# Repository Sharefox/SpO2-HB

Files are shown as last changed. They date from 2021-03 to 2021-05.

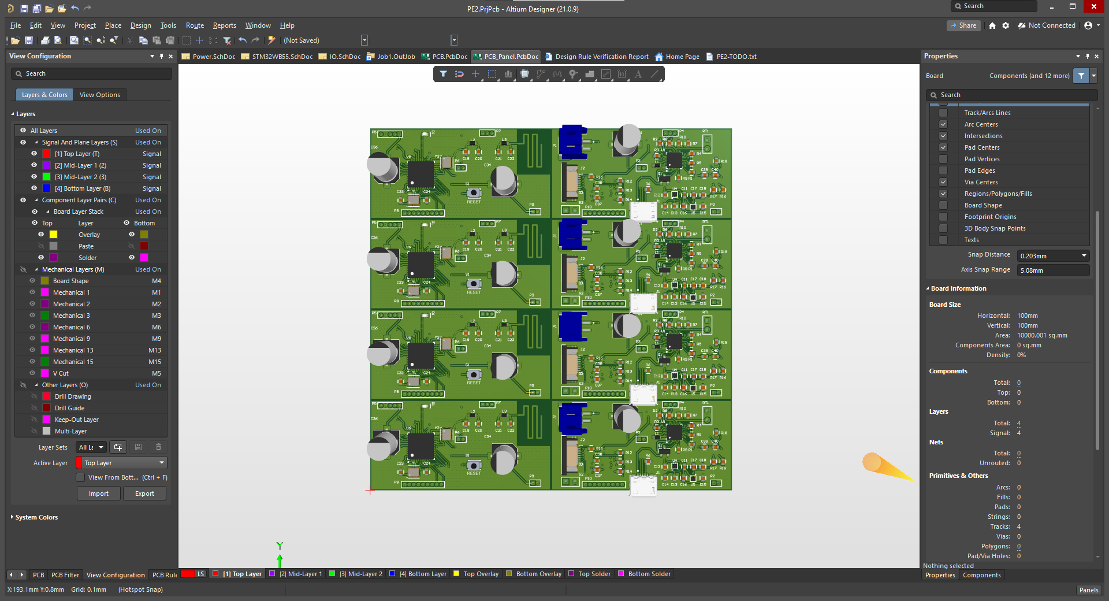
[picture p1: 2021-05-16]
PCB/PE2/Panel.png

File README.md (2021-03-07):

# SpO2/HB

 <br />
 <p align="center">
   <a href="https://github.com/Sharefox/SpO2-HB">
     
   </a>

   <h3 align="center">SpO2/HB measuring device</h3>

   <p align="center">
      Practice Enterprise 2 Heartbeat and Oxygen saturation sensor with Bluetooth functionality
     <br />
     <a href="https://github.com/Sharefox/SpO2-HB"><strong>Explore the docs »</strong></a>
     <br />
     <br />
     <a href="https://github.com/Sharefox/SpO2-HB">View Demo</a>
     ·
     <a href="https://github.com/Sharefox/SpO2-HB/issues">Report Bug</a>
     ·
     <a href="https://github.com/Sharefox/SpO2-HB/issues">Request Feature</a>
   </p>
 </p>

 <!-- TABLE OF CONTENTS -->
 <details open="open">
   <summary><h2 style="display: inline-block">Table of Contents</h2></summary>
   <ol>
     <li><a href="#about-the-project">About The Project</a></li>
     <li><a href="#usage">Usage</a></li>
     <li><a href="#roadmap">Roadmap</a></li>
     <li><a href="#contributing">Contributing</a></li>
     <li><a href="#license">License</a></li>
     <li><a href="#contact">Contact</a></li>
     <li><a href="#acknowledgements">Acknowledgements</a></li>
   </ol>
 </details>

 <!-- ABOUT THE PROJECT -->
## About The Project

 [![Product Name Screen Shot][product-screenshot]](https://example.com)

 With the covid19 virus it became apparent that there is a need for Home Monitoring. Doctors noted severe damage in patients' lungs, even when the patient had no symptoms. Also the oxygen saturation was shocking for most.
 With this project we would like to make sure people have an option to measure their saturation at home when they have corona but are too healthy to stay in the hospital.
 In this way we hope to avoid the worst by noticing in time what's going on.

 <!-- USAGE EXAMPLES -->
## Usage

 Use this space to show useful examples of how a project can be used. Additional screenshots, code examples and demos work well in this space. You may also link to more resources.

 _For more examples, please refer to the [Documentation](https://example.com)_

 <!-- ROADMAP -->
## Roadmap

 See the [open issues](https://github.com/Sharefox/SpO2-HB/issues) for a list of proposed features (and known issues).

 <!-- CONTRIBUTING -->
## Contributing

 Contributions are what make the open source community such an amazing place to be, learn, inspire, and create. Any contributions you make are **greatly appreciated**.

 1. Fork the Project
 2. Create your Feature Branch (`git checkout -b feature/AmazingFeature`)
 3. Commit your Changes (`git commit -m 'Add some AmazingFeature'`)
 4. Push to the Branch (`git push origin feature/AmazingFeature`)
 5. Open a Pull Request

 <!-- LICENSE -->
## License

 Distributed under the GNU License. See `LICENSE` for more information.

 <!-- CONTACT -->
## Contact

 Sharefox - Glenn Adriaensens - glenn.adri@hotmail.com <br />
 Liesjelotje98 - Lieselotte Verhulst - lieselotte.verhulst98@gmail.com

 Project Link: [https://github.com/Sharefox/SpO2-HB](https://github.com/Sharefox/SpO2-HB)

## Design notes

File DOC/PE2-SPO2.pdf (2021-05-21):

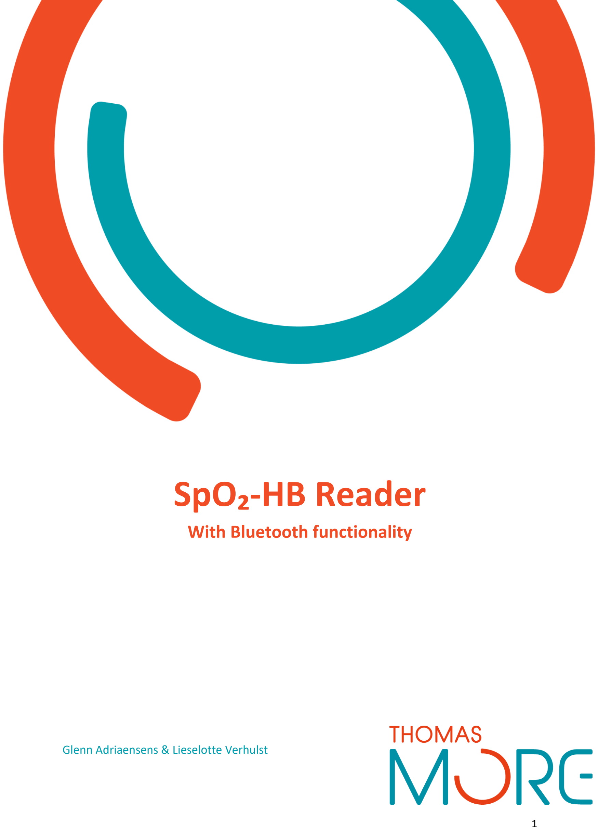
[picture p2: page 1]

# SpO₂-HB Reader

## With Bluetooth functionality

Glenn Adriaensens & Lieselotte Verhulst

## Voorwoord

In de keuze voor ons project werden we, in volle coronapandemie, geleid door berichten die ons sterk aangegrepen hebben.
Het huidige coronavirus was volledig nieuw en er bestond bijgevolg geen enkele medisch-wetenschappelijke kennis.
Vooral tijdens de beginfase van de pandemie, toen er nog geen diagnostische testing mogelijk was, werden spoedartsen vaak verrassend geconfronteerd met zeer ver gevorderde longaantasting bij de patiënten.
Enerzijds vond men zeer ernstige ziektetekens op de longfoto’s (CT-scan), maar anderzijds stelde men vast dat die patiënten bij opname een zeer laag zuurstofgehalte in hun bloed vertoonden, zonder dat ze tijdens de voorafgaande periode ziektesymptomen hadden opgemerkt.

In dit kader groeide bij ons het idee om te werken aan een project, waardoor meting van de zuurstofsaturatie in het bloed voor iedereen toegankelijk wordt.
Het was onze bedoeling dit meettoestel betaalbaar te maken voor het grote publiek, maar dit is moeilijker gebleken dan we gedacht hadden.

We weten dat de meting niet gebeurt met eenzelfde precisie als in ziekenhuizen, maar dergelijke vorm van zelfmonitoring / thuismonitoring helpt wel in de vroegtijdige preventie van longbeschadiging door dit virus.

Bij het debuggen van hardware en software hebben we wel wat moeilijkheden ondervonden.
We hebben veel geleerd uit dit project, en we vonden het bijzonder boeiend om op ontdekking te gaan in de wereld waar medische techniek en elektronica elkaar ontmoeten.

We zouden graag Mr. Wim Dams en Mr. Nick Steen willen bedanken om onze vragen te beantwoorden, evenals Mr. De Weerdt voor de hulp bij het bestukken van de PCB.

## Inhoudsopgave

## Projectvoorstel/ Inleiding

Kort gezegd is het de bedoeling dat ons project de hartslag en de zuurstofsaturatie meet, deze dan toont op een OLED scherm, en via bluetooth doorstuurt naar de gsm.

### Blokschema

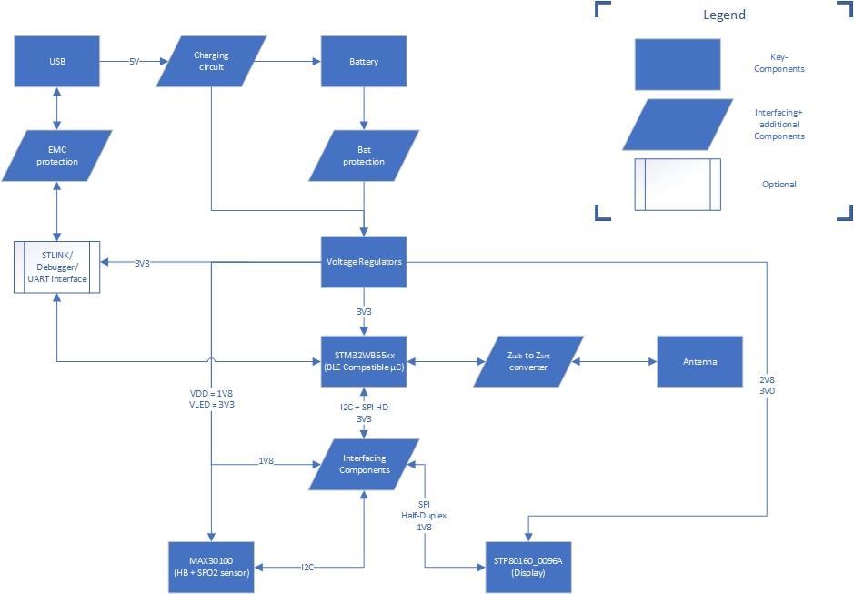
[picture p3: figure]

Figuur 1: Uitgebreid blokschema

De USB is een micro-USB aansluiting om enerzijds het project op te laden en anderzijds de microcontroller te kunnen programmeren.
We gebruiken een oplaadbare batterij en hierbij voorzien we een galvanische scheiding en een voltage regulator.

STM32WB55 is de microcontroller.
De gemeten waarden worden via de microcontroller doorgestuurd naar het LCD, en eveneens naar de bluetooth module, zodat ze naar de gsm kunnen worden opgestuurd.

De sensor die we gebruiken is de MAX30102, deze meet de hartslag en zuurstofwaarde.

Voor het OLED gebruiken we een STP80160. Dit is een OLED scherm van 160x80 pixels.
Hierop worden uitsluitend de gemeten waarden van de hartslag en van de zuurstofsaturatie aangebracht.

### Principe perifere O₂-Saturatiemeter

De perifere O₂-saturatiemeter (in combinatie met de hartslagmeter) is een medisch-technisch meetinstrument.

Zuurstofsaturatie:

Onze ademhalingsfunctie zorgt ervoor, dat voldoende zuurstof via de longen in ons bloed terecht komt, om vervolgens alle lichaamsorganen te kunnen bereiken.
In ons bloed wordt zuurstof getransporteerd door hemoglobine, een eiwit dat de O₂-moleculen aan zich bindt.
De zuurstofsaturatie (letterlijk: verzadiging) geeft de verhouding aan tussen het hemoglobinegehalte dat O₂-moleculen draagt, en het totale gehalte aan hemoglobine in het bloed.
hemoglobine dat O₂ draagt | OF | geoxygeneerd hemoglobine
totaal hemoglobine | | totaal hemoglobine

Die verhouding wordt uitgedrukt door een percentage %.

Nog even verduidelijken dat men de zuurstofsaturatie meet in het “perifeer” bloed. Dit wil zeggen dat men meet ter hoogte van de (kloppende) bloedvaatjes van een perifeer lichaamsdeel vb. een
vingertop, | een | oorlel.
Daarom spreken we over de SpO₂-meting (in tegenstelling tot de SaO₂-meting, die men in ziekenhuizen uitvoert door het rechtstreeks aanprikken van een slagader).

Werkingsprincipe van het meetinstrument :

De werking van de saturatiemeter is gebaseerd op fotometrie.

Een lichtbundel wordt aan één zijde van vb. de vingertop geplaatst, zodat deze doorheen de perifere bloedvaatjes gezonden wordt.
Men gebruikt een rode LED met een golflengte van 660nm en een infrarode LED met een golflengte van 940nm.
Licht van deze beide golflengten wordt anders geabsorbeerd door geoxygeneerd bloed dan door niet-geoxygeneerd bloed:
geoxygeneerd hemoglobine absorbeert meer IR licht en laat meer rood licht door, terwijl het net omgekeerd is voor niet-geoxygeneerd bloed.

Een fotodiode detecteert het deel van de lichtbundel, dat niet ter hoogte van de bloedvaatjes werd geabsorbeerd.

De verhouding tussen de uitgezonden lichtbundel, en de lichtbundel die niet geabsorbeerd werd en dus gedetecteerd door de fotodiode, kan dan omgerekend worden naar de zuurstofsaturatie.

Hartslagmeter :

De hartslag kan tegelijkertijd gemeten worden omdat het lichtsignaal de variatie van de hartslag volgt: bij elke hartslag stroomt er immers een groot debiet (pulse) doorheen de bloedvaatjes.

De combinatie van de perifere zuurstofsaturatiemeter en de hartslagmeter wordt dan ook de pulsoxymeter genoemd.

## Componenten

STM32WB55CG
48-pin Bluetooth-compatible chip 1Mbyte flash
256K RAM

MAX8903A
28-pin battery management chip
Overvoltage protection
USB input -> No reverse voltage
Battery charge current and SYS output current limit are independently set

LD39050PU33R
6-pin 500mA voltage regulator
Input 1V5 -> 5V5
Max 500mA output -> 1.65W [ 3V3 x 0.5A]

MIC5502-1.8YMT
4-pin 300mA voltage regulator
Input 1V8 -> 5V5
Max 300mA output -> 0.54W [ 1V8 x 0.3A]

MIC5502-2.8YMT
4-pin 300mA voltage regulator
Input 2V8 -> 5V5
Max 300mA output -> 0.84W [ 2V8 x 0.3A]

LFB182G45BG4D268
6-pin Balance matching bandpass filter 2450.00MHz ± 50.00 MHz

TXB0108PWR
20-pin 8-bit Bidirectional voltage-level translator
1V2 to 3V6 on A-port and 1V65 to 5V5 on B-port VCCA mag niet hoger zijn dan VCCB

MAX30102
14-pin Pulse oximeter and heart-rate sensor

## Hardware

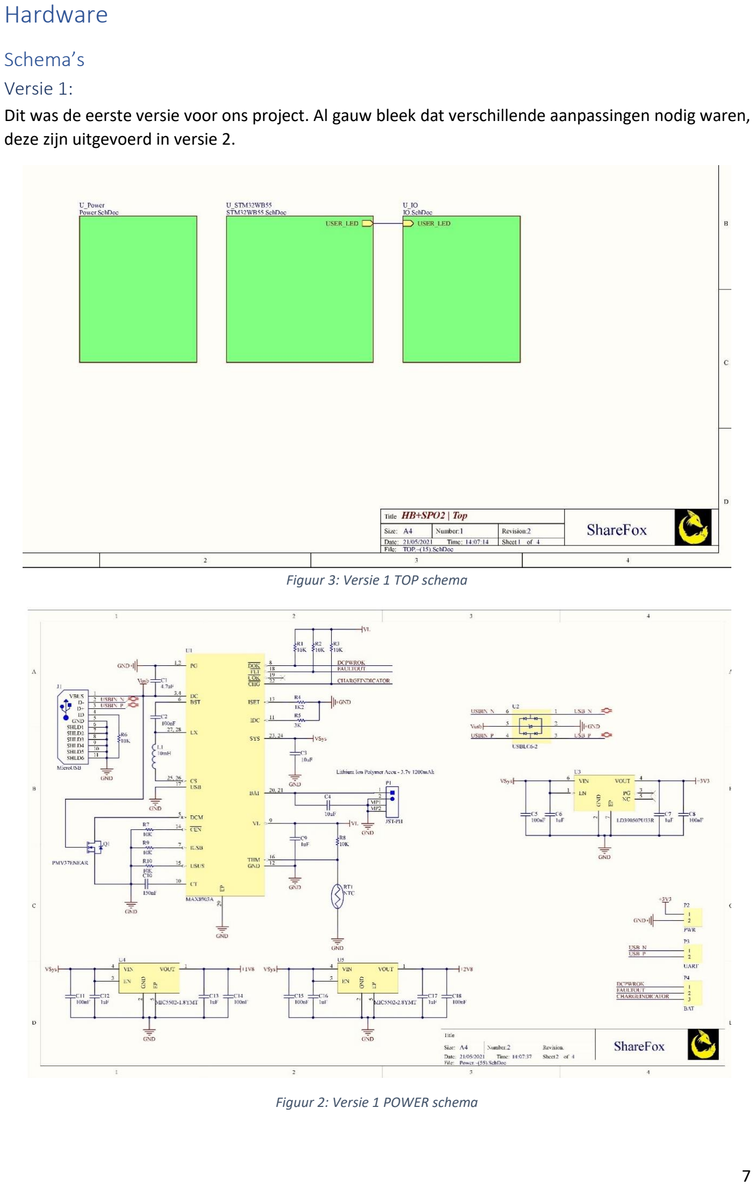
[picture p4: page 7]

### Schema’s

Versie 1:
Dit was de eerste versie voor ons project. Al gauw bleek dat verschillende aanpassingen nodig waren, deze zijn uitgevoerd in versie 2.

Figuur 2: Versie 1 POWER schema

Figuur 3: Versie 1 TOP schema

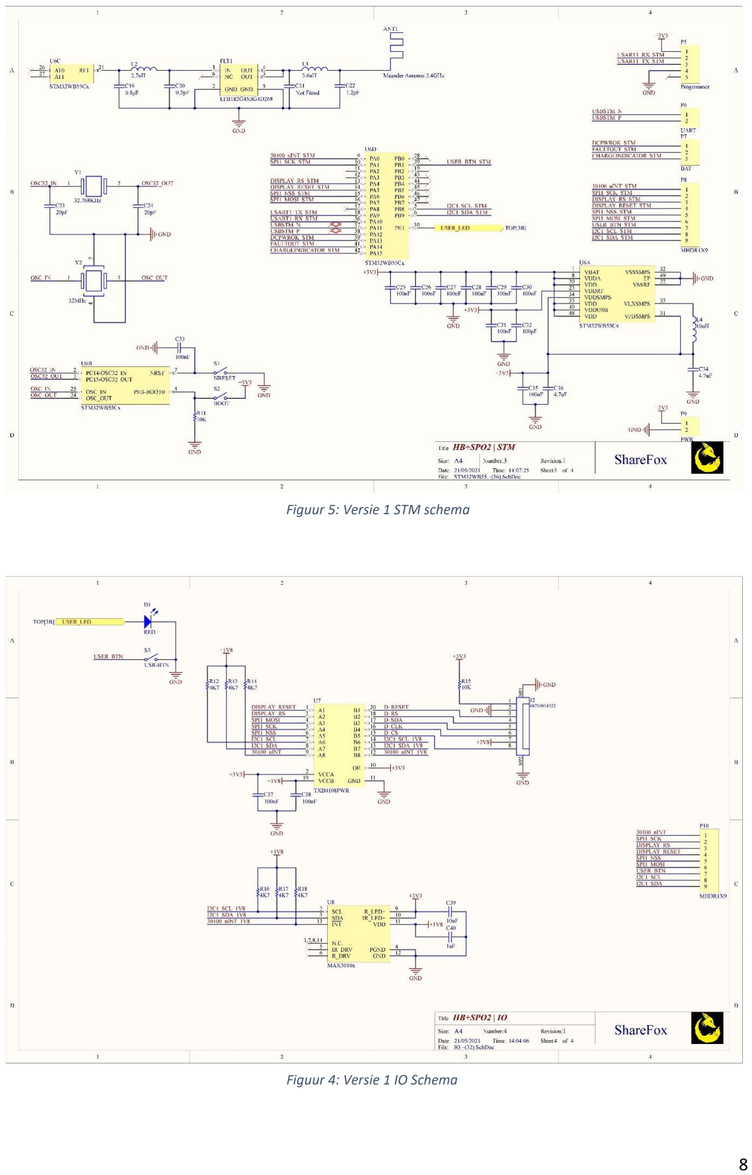
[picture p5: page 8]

Figuur 4: Versie 1 IO Schema

Figuur 5: Versie 1 STM schema

Versie 2:
Dit is de huidige versie, door tijdsredenen hebben we deze PCB niet kunnen laten fabriceren.
We hebben een breakout board gemaakt om de tests te kunnen uitvoeren en om een demo te geven.
Volgende aanpassingen hebben we doorgevoerd (zie pagina “HB+SPO2 | Power”):
- Spoel “L1” is veranderd van 10mH naar 2.2µH. De standwaarde was niet aangepast.
- | De | N-channel | MOSFET | werd | aangepast | naar | een | pulldown | weerstand.
Verder diende de level translator “U7” te worden aangepast (zie pagina “HB+SPO2 | IO”): in Versie 1
was VCCA > VCCB, maar de datasheet vereist VCCA ≤ VCCB.

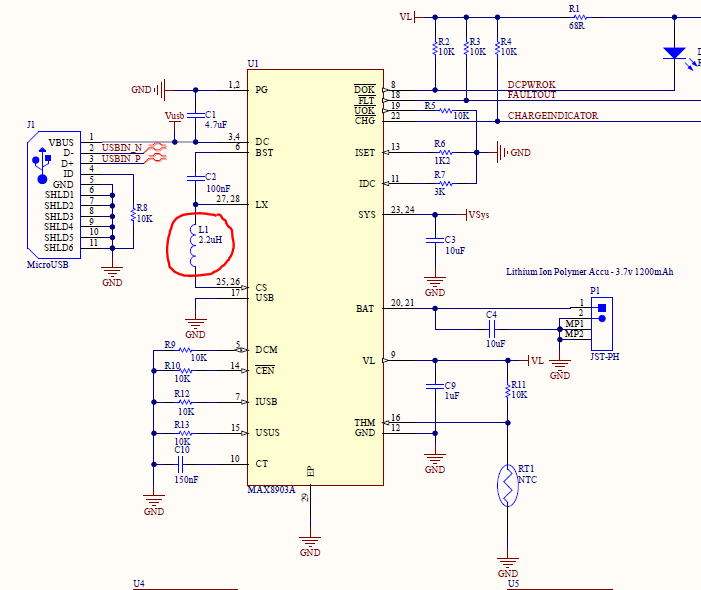
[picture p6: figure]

Figuur 6: L1 aanpassing

Breakout board:
Op het breakout board, dat we voorzien hebben wegens tijdsgebrek, staat uitsluitend de randapparatuur; deze wordt aangestuurd door een P-NUCLEO-WB55 bord.

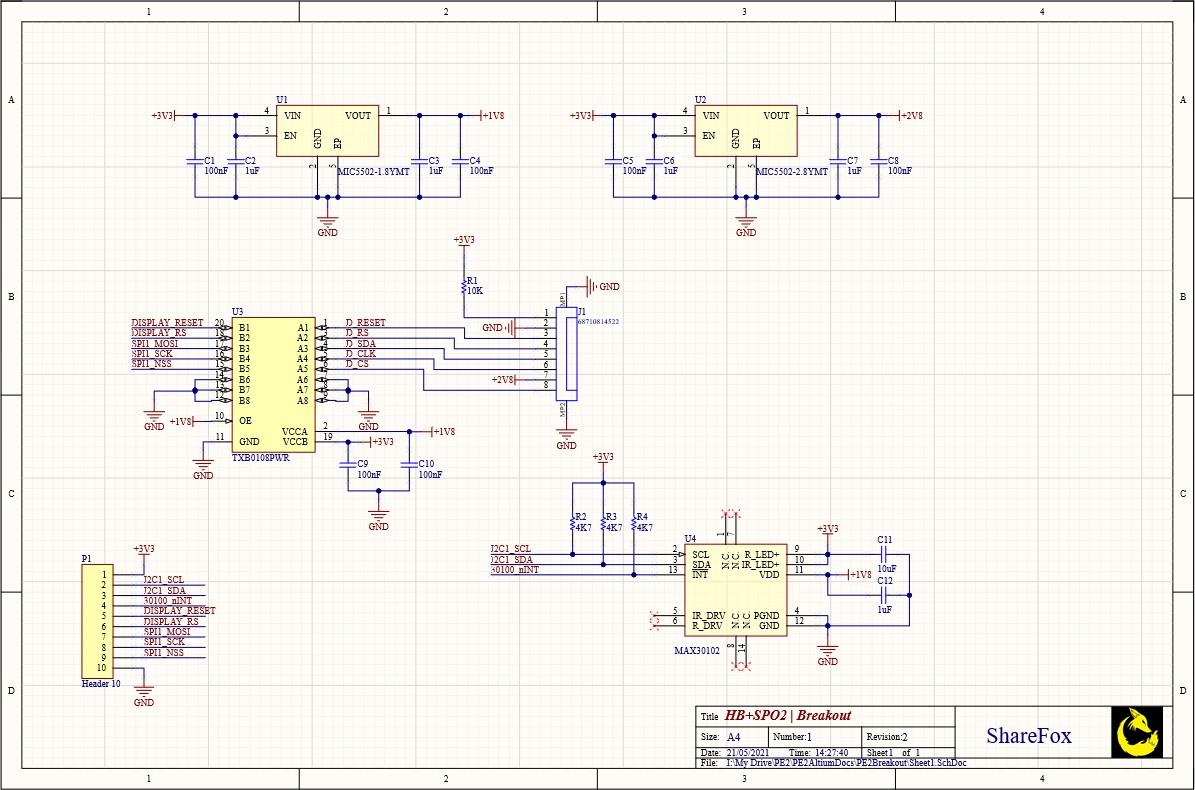
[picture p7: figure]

Figuur 7: Breakout Board Schema

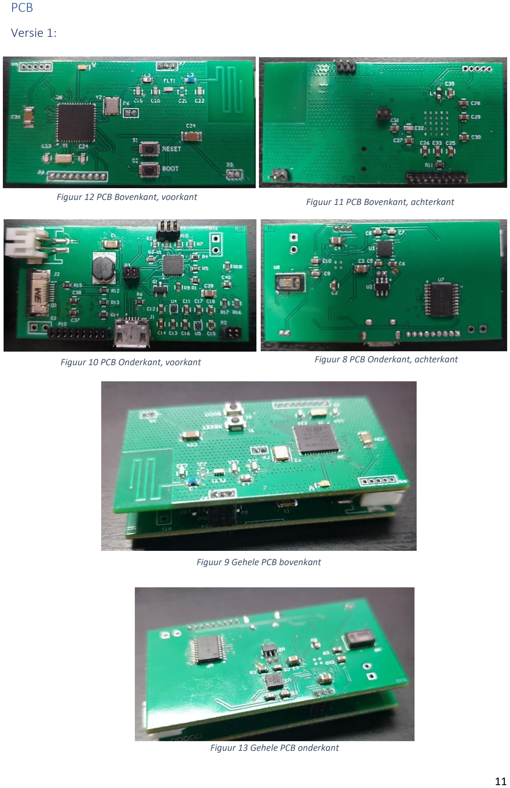
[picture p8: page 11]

### PCB

Versie 1:

Figuur 12 PCB Bovenkant, voorkant | Figuur 11 PCB Bovenkant, achterkant
Figuur 10 PCB Onderkant, voorkant | Figuur 8 PCB Onderkant, achterkant

Figuur 9 Gehele PCB bovenkant

Figuur 13 Gehele PCB onderkant

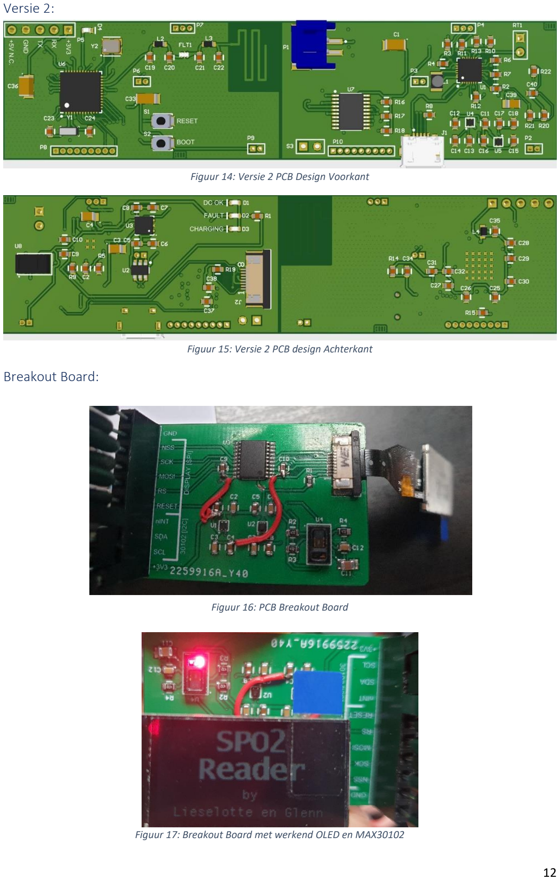
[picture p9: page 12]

Versie 2:

Figuur 14: Versie 2 PCB Design Voorkant

Figuur 15: Versie 2 PCB design Achterkant

Breakout Board:

Figuur 17: Breakout Board met werkend OLED en MAX30102

Figuur 16: PCB Breakout Board

### CAD

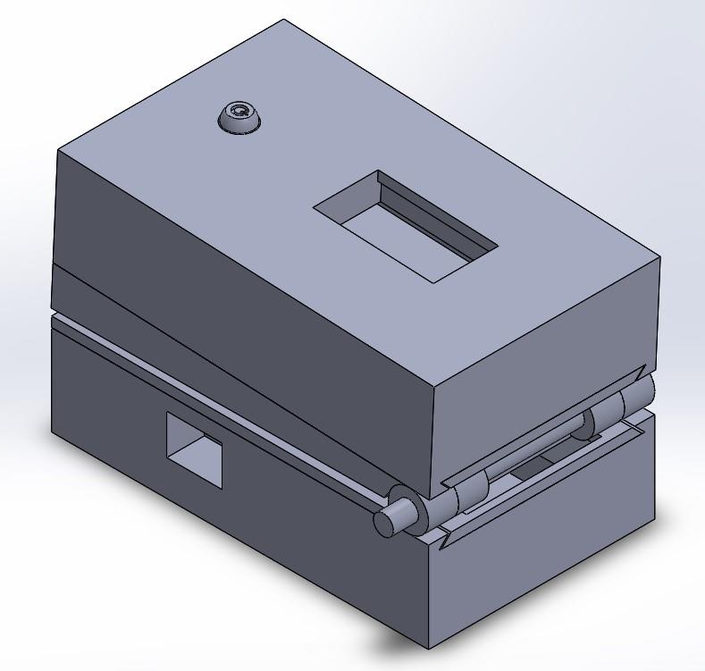
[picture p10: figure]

Figuur 18: Behuizing CAD

## Software

### SpO₂-Sensor

De “MAX30102-sensor” is een chip, waarmee men de hartslag en het O₂-saturatiegehalte kan meten, en dit door middel van een IR en RED led.

In de software voeren we verschillende configuraties uit voor de chip.
Vooreerst dienen de interrupts, die we wensen te gebruiken, ingeschakeld te worden, omdat deze standaard uitgeschakeld staan.
Vervolgens starten we de sensor op, hierbij wissen we alle informatie die zich in de FIFO registers bevindt; hiertoe behoren: FIFO write pointer, FIFO read pointer, FIFO overflow en FIFO data.
Als laatste stap van de configuratie, stellen we de waarden in waarmee we de chip willen gebruiken.

Voor onze toepassing geldt:

Sample Average | 8
Mode | SPO₂
ADC RGE | 4096
SPO2 sample rate | 400
Led Puls width | 118
Led Amplitude | 0x7F = …mA
Temp_en | enable

Hieruit volgt dat we 50 samples per seconde zullen inlezen.

SpO₂ sample rate / Sample Average = sample per seconde

Tenslotte wachten we nog op eventueel binnenkomende interrupts.

Omdat we de modus SpO₂ gebruiken (en dus niet enkel de hartslag), moeten we de temperatuur van de chip kennen.
Het is belangrijk dat we deze waarde kennen omdat de temperatuur invloed heeft op de golflengte van de rode LED, en bijgevolg ook op de door ons ingelezen data.
Omdat we Temp_en hebben ingeschakeld in de configuratie,zal de chip de temperatuur meten en een interrupt sturen wanneer de data klaar zijn om uit gelezen te worden.

De temperatuur wordt opgeslagen in 2 registers. Het eerste register bevat het geheel getal (INT) en het tweede register bevat het kommagetal (FRAC). We voegen deze 2 waarden bij elkaar door de formule uit de datasheet.
Tgemeten = INT + FRAC * 0.0625

De data van de MAX30102 worden opgeslagen in een FIFO register. Dit register is 6 bytes diep en kan 32 samples opslaan. Wanneer we dit register willen lezen, moeten we eerst weten hoeveel samples er aanwezig zijn. We kijken daarom naar het adres dat de Read pointer en de Write pointer aanwijzen.

Aantal leesbare samples = WritePtr – ReadPtr

De lezing van 1 sample vergt 6x lezing op dezelfde plaats in het register. De Read pointer bij dit register wordt verhoogd bij elke eerste byte die wordt gelezen van de 6.

De data, die we op deze manier uit de chip lezen, plaatsen we vervolgens in een buffer, zodat we ze erna kunnen gebruiken voor de berekeningen.

Vooreerst gaan we 4 seconden data, zijnde 200 samples, analyseren. Zo wordt er een signaal range vastgesteld, waar we de volgende berekeningen zich op baseren. Vervolgens wordt om de seconde een nieuwe berekening uitgevoerd.

### Interrupts MAX30102

Er zijn 5 verschillende interrupts die kunnen worden opgeroepen, deze zijn onderverdeeld in 2
registers. | In | de | datasheet | is | terug | te | vinden | welke | interrupts | waar | staan.
De chip trekt de interruptlijn laag, waarna men de registers gaat lezen om te zien welke interrupt hier voor heeft gezorgd.
1. A_FULL, dit is de FIFO Almost Full Flag.
Op het ogenblik dat in de FIFO nog maar een bepaald aantal vrije plaatsen over blijven voor
samples, | wordt | deze | interrupt | opgeroepen.
Men kan zelf instellen vanaf welk aantal vrij overblijvende plaatsen de interrupt wordt opgeroepen (in FIFO_A_FULL[3:0]).
2. PPG_RDY
Deze interrupt staat voor New FIFO Data Ready.
Telkens wanneer een nieuwe sample aanwezig is wordt deze interrupt gezet.
3. ALC_OVF
Deze interrupt staat voor Ambient Light Cancellation Overflow.
Dit wordt getoond vanaf het ogenblik waarop te veel licht de output van deADC beïnvloedt.
4. PWR_RDY
Bij opstarten en bij een brownout conditie wordt deze interrupt aangezet vanaf het ogenblik waarop we opnieuw data kunnen lezen.
5. DIE_TEMP_RDY
Deze interrupt staat voor Internal Temperature Ready Flag.
Wanneer de temperatuur is gemeten en kan worden uitgelezen, zal deze interrupt gezet worden.

Al deze interrupts worden gecleared wanneer het register van de interrupt gelezen wordt.

### OLED scherm

We gebruiken een OLED scherm met een ST7735S driver.
Wanneer we het OLED scherm willen gebruiken moeten we het scherm aanzetten, initialiseren en
aangeven | op | welke | coördinaten | we | data | naar | het | scherm | willen | schrijven.
We hebben het scherm ingedeeld in aparte vakjes, zodat we niet altijd het gehele scherm moeten overschrijven, maar uitsluitend de delen die veranderen.

### Bluetooth

We maken gebruik van BLE oftewel Bluetooth Low Energy.
Allereerst moet er verbinding gemaakt worden tussen de app en de PCB. Wanneer dit gelukt is zal er om de minuut een update van de hartslag & saturatie gestuurd worden naar de app. Deze app houdt dan de data bij.
We gebruiken de sequencer om dit uit te voeren. Zo zorgen we dat er geen data verloren gaat gaan en dat het programma efficiënter kan functioneren.
Elke minuut wordt er data van de µC naar de app gestuurd.
Er worden 4 bytes naar de app gestuurd, 2 bytes voor de timestamp en dan 2 bytes voor de waarde van Hartslag en de Saturatiewaarde.

### BLE

Bluetooth Low Energy is een wireless streaming van data.

Basis principes:
GAP layer
→ controleert ‘advertising’ en ‘connections’, dit zorgt er voor dat het apparaat zichtbaar is voor de buitenwereld.
→ beslist ook hoe 2 apparaten met elkaar kunnen communiceren.

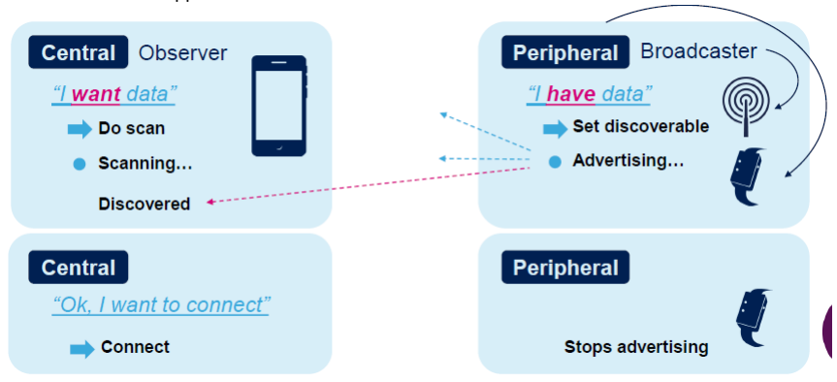
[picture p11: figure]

Figuur 19: GAP Layer

GATT:
Generic Attribute Profile
→ definieert hoe 2 BLE apparaten met elkaar data uitwisselen.

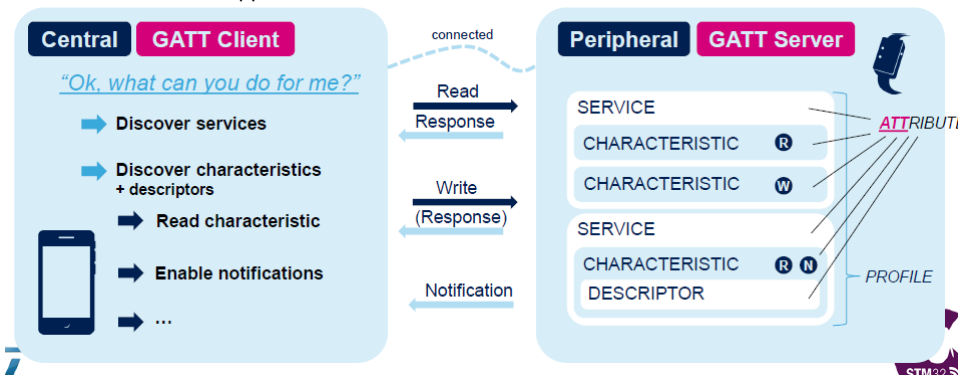
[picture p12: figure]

Figuur 20: GATT Layer

Voegt een data model en hiërarchie toe op de ATT
GATT service is een container voor logische gerelateerde data items.
GATT characteristics zijn logisch gerelateerde data items binnen in 1 service.

ATT:
Attribute Protocol
Cliënt/server protocol, vormt de basis van de data uitwisseling in BLE applicaties.
De server biedt data aan op request van de cliënt.
De server data worden opgeslagen in de ‘attribute table’, deze bevat een serie van records van verschillende types. De belangrijkste zijn ‘services’ en ‘characteristics’

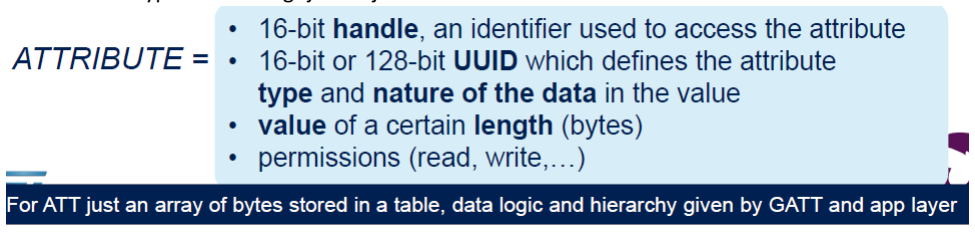
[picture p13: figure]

Figuur 21: Attribute

De naam van de server, in dit geval onze microcontroller, kunnen we zelf instellen. Hier is de naam “98-NODE”. Dit is de naam waarmee we verbinding moeten maken op de gsm.

Voor de BLE gebruiken we de sequencer/ scheduler als een basic task manager.

De AD structuur van het BlueST Protocol:

Dit heeft een bepaalde formatting die we moeten respecteren.

Figuur 22: AD structuur BlueST Protocol

Wanneer je hier een custom bord gebruikt, moet je een device ID gebruiken, die nog niet aangewezen is.
Feature mask geeft informatie over de aard van de data die door het bord worden uitgestuurd.
De STM heeft er hier 32 voorgeprogrammeerd. Wij gebruiken de ‘temperature’ feature mask, omdat die manier waarop data gestuurd worden het meest aansluit bij ons project.

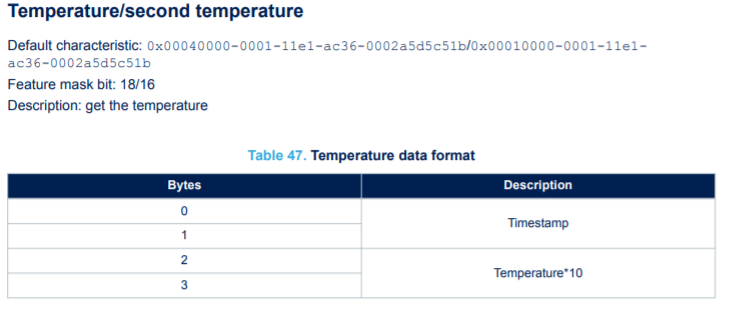
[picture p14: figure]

Figuur 23: Feature Mask

De CubeMX genereert reeds de meeste code voor de BLE. Wij moeten wel nog onze eigen applicatie hieraan toevoegen. (onze eigen applicatie dient hier nog aan toegevoegd.)
We voegen dus zelf een GATT toe. Hierin geven we aan welke soort data we willen sturen/ontvangen. We voegen een scheduler task toe en registreren die onder een bepaalde prioriteit. Zo ook is er een timer, die er voor zorgt dat de gestuurde data slechts om de minuut worden gestuurd. D

Deze timer is ingesteld op 1 minuut, dit vereenvoudigd het testen.

## Kwaliteitscontrole

### Problemen/Oplossingen:

Probleem: | Oplossing:
Batterij wordt kortgesloten als men probeert op te laden. | Tijdelijk: 5V Trace naar batterij management chip doorgesneden.
STM32WB55 kan niet consistent geprogrammeerd worden (componenten kunnen hierdoor niet getest worden) | Tijdelijk: Breakout board voor randapparatuur gemaakt.
De level shifter gaf geen signaal door. | VCCA en VCCB moesten gewisseld worden → Level shifter werkt.

## Besluit

Het was een interessant maar moeilijk project. Enigszins hebben we veel bijgeleerd, zeker over PCB design, bestukken en de medische wereld in de elektronica. De moeilijkheid lag bij ons bij time Management. We waren op tijd begonnen en vonden dat we goed op schema zaten maar dan hebben we een paar tegenslagen tegengekomen met de hardware waardoor we eigenlijk pas heel laat de code hebben kunnen testen en daar bleek dan ook nog vanalles fout te gaan.

We vonden het beiden wel een aangename samenwerking omdat we over de gehele lijn toch op dezelfde golflengte zaten.

We onthouden voor de volgende projecten om sneller een plan B achter de hand te houden.

## Bijlagen

### Lijst afbeeldingen

### Bronvermelding

MCU:
https://www.st.com/resource/en/datasheet/stm32wb55cg.pdf
Battery management chip:
https://datasheets.maximintegrated.com/en/ds/MAX8903-MAX8903Y.pdf +3V3 voltage regulator:
https://www.st.com/resource/en/datasheet/ld39050.pdf
+1V8 & +2V8 voltage regulator: https://ww1.microchip.com/downloads/en/DeviceDoc/MIC5501-02-03-04-300mA-Single-Output-LDO-in-Small-Packages-DS20006006B.pdf (https://ww1.microchip.com/downloads/en/DeviceDoc/MIC5501-02-03-04-300mA-Single-Output-LDO-in-Small-Packages-DS20006006B.pdf)
Band-pass filter:
https://www.murata.com/en-global/api/pdfdownloadapi?cate=luLCBalancedFilter&partno=LFB182G45BG4D268 (https://www.murata.com/en-global/api/pdfdownloadapi?cate=luLCBalancedFilter&partno=LFB182G45BG4D268) Voltage level shifter
https://www.ti.com/lit/gpn/TXB0108
Pulse Oximeter and Heart-Rate Sensor: https://datasheets.maximintegrated.com/en/ds/MAX30102.pdf

https://www.st.com/resource/en/user_manual/dm00550659-getting-started-with-the-bluest-protocol-and-sdk-stmicroelectronics.pdf (https://www.st.com/resource/en/user_manual/dm00550659-getting-started-with-the-bluest-protocol-and-sdk-stmicroelectronics.pdf)

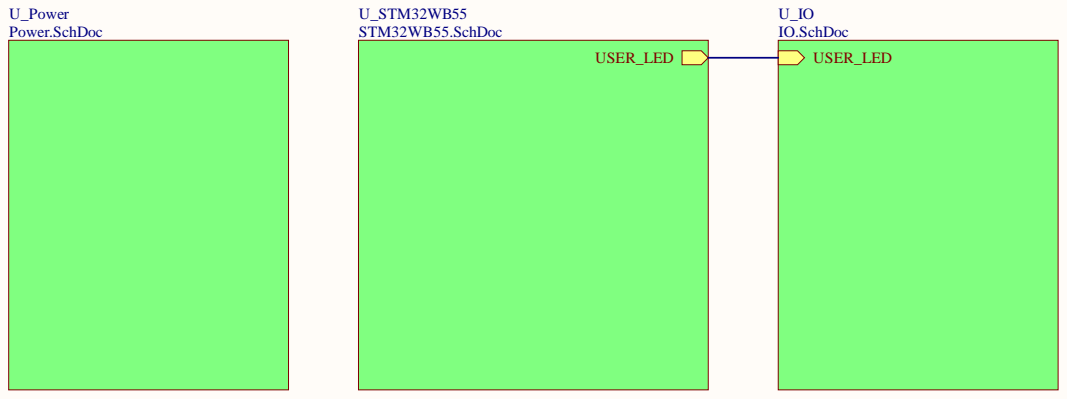
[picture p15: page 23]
Size:; Number:; Date: File:; Revision:; Time:; Sheet; ShareFox; USER_LED; U_IO IO.SchDoc; U_Power Power.SchDoc; U_STM32WB55 STM32WB55.SchDoc

HB+SPO2 | Top
Title
C:\Users\Public\Documents\Altium\Projects\PE2\TOP.SchDoc

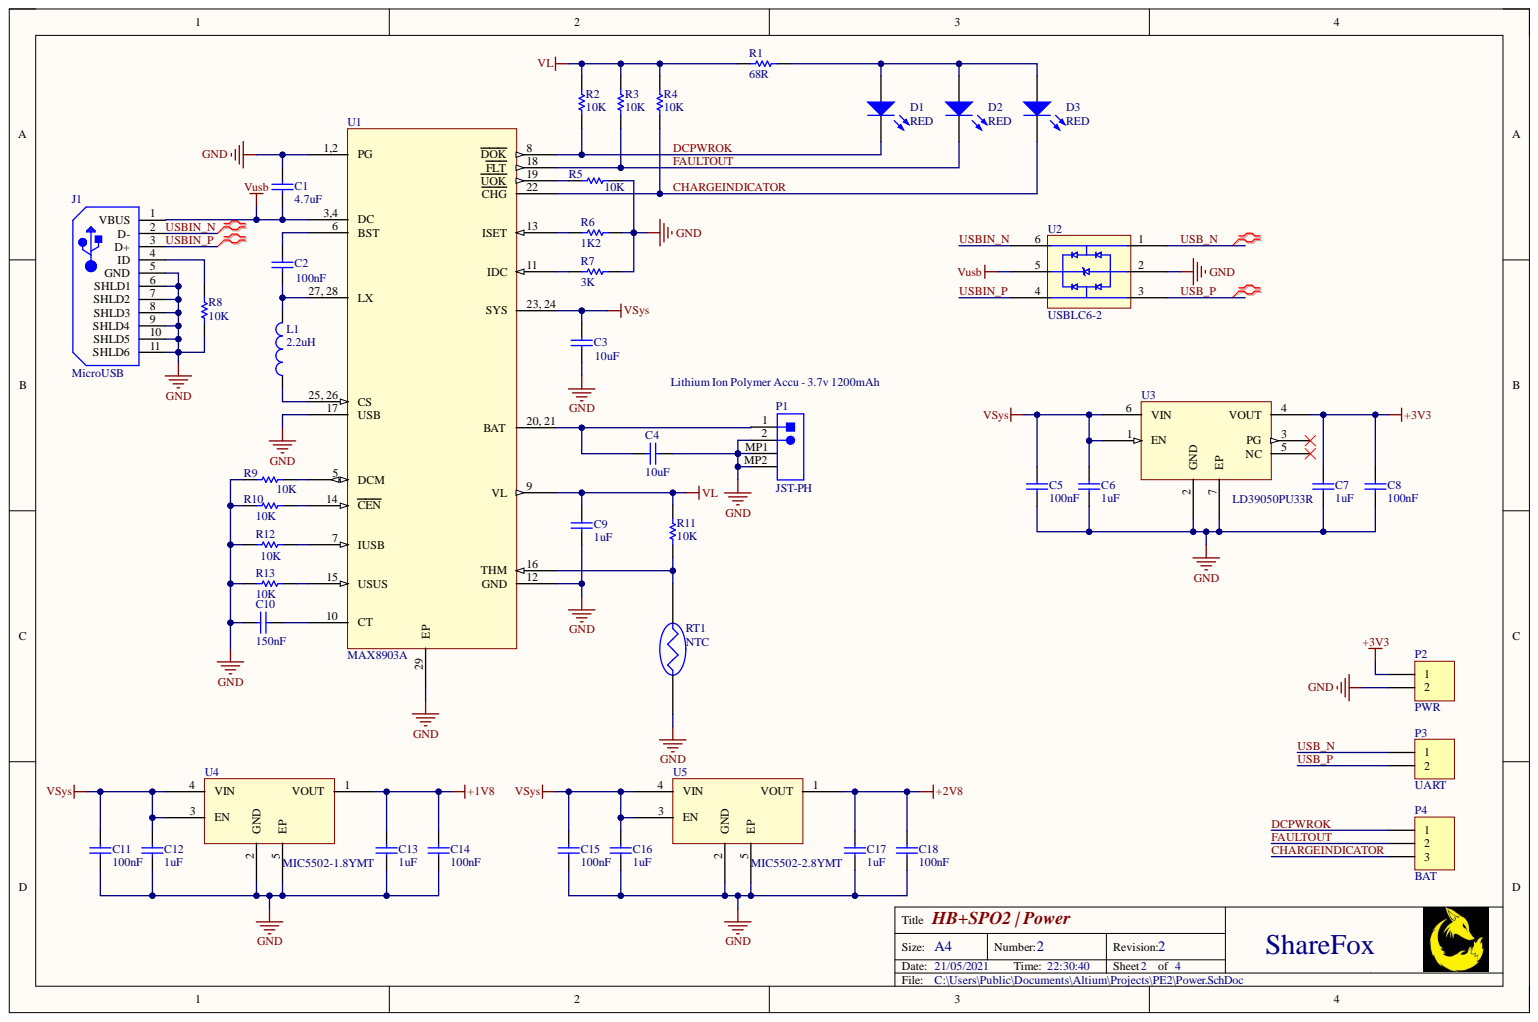
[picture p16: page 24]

Lithium Ion Polymer Accu - 3.7v 1200mAh

HB+SPO2 | Power
Title
C:\Users\Public\Documents\Altium\Projects\PE2\Power.SchDoc

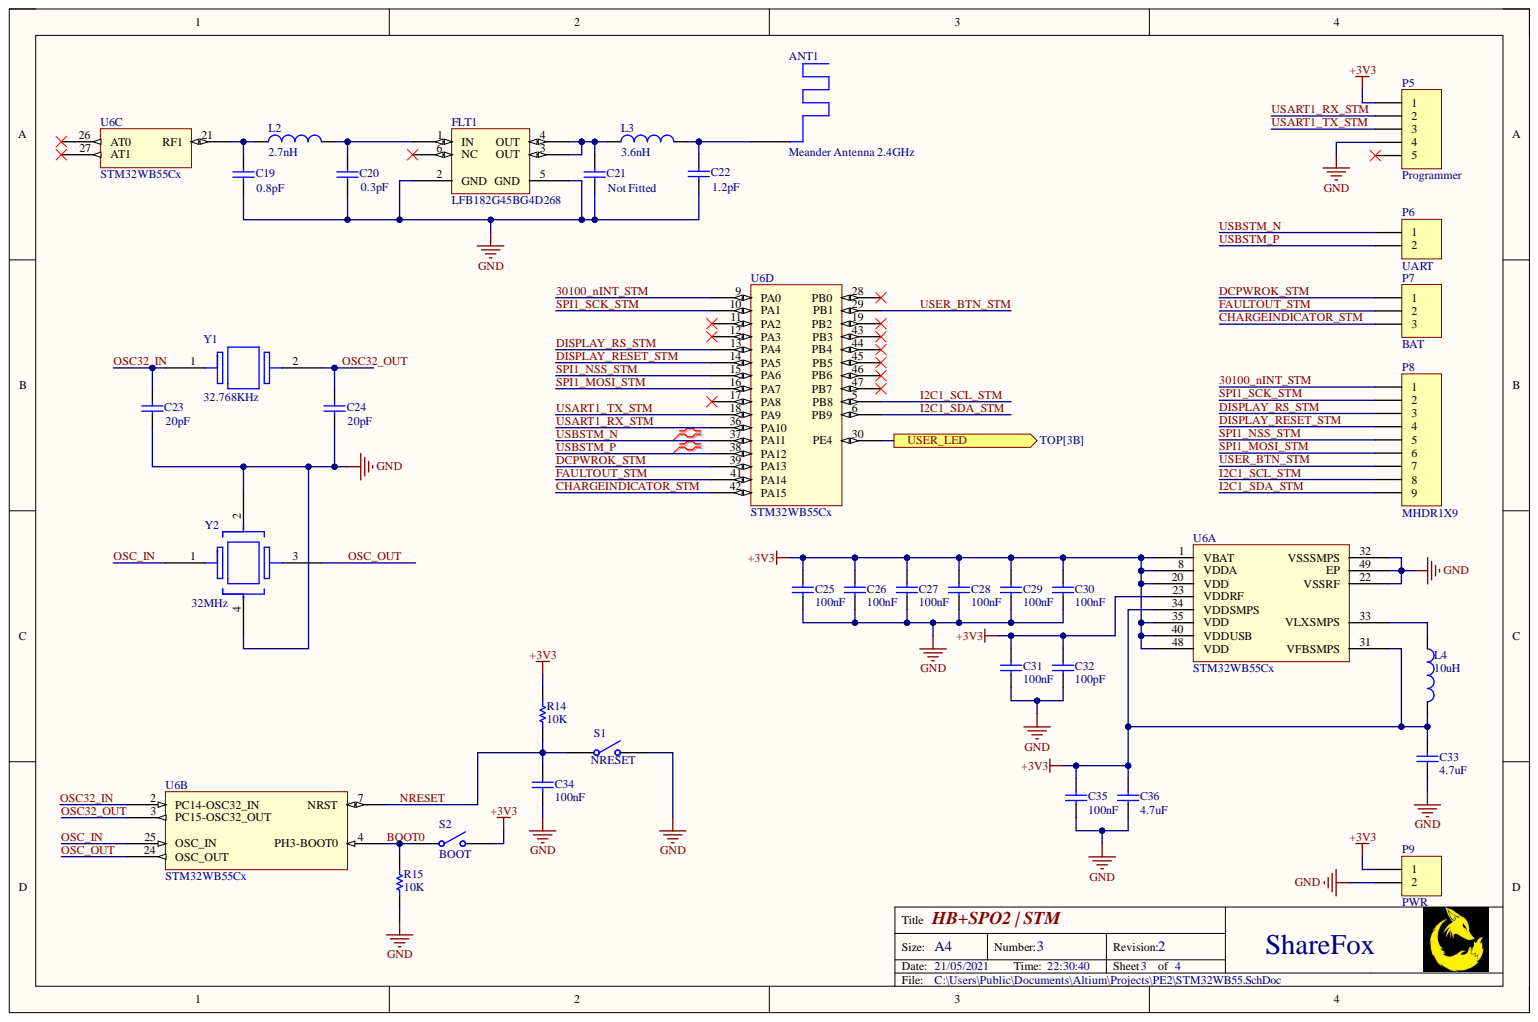
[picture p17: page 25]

HB+SPO2 | STM
Title
C:\Users\Public\Documents\Altium\Projects\PE2\STM32WB55.SchDoc

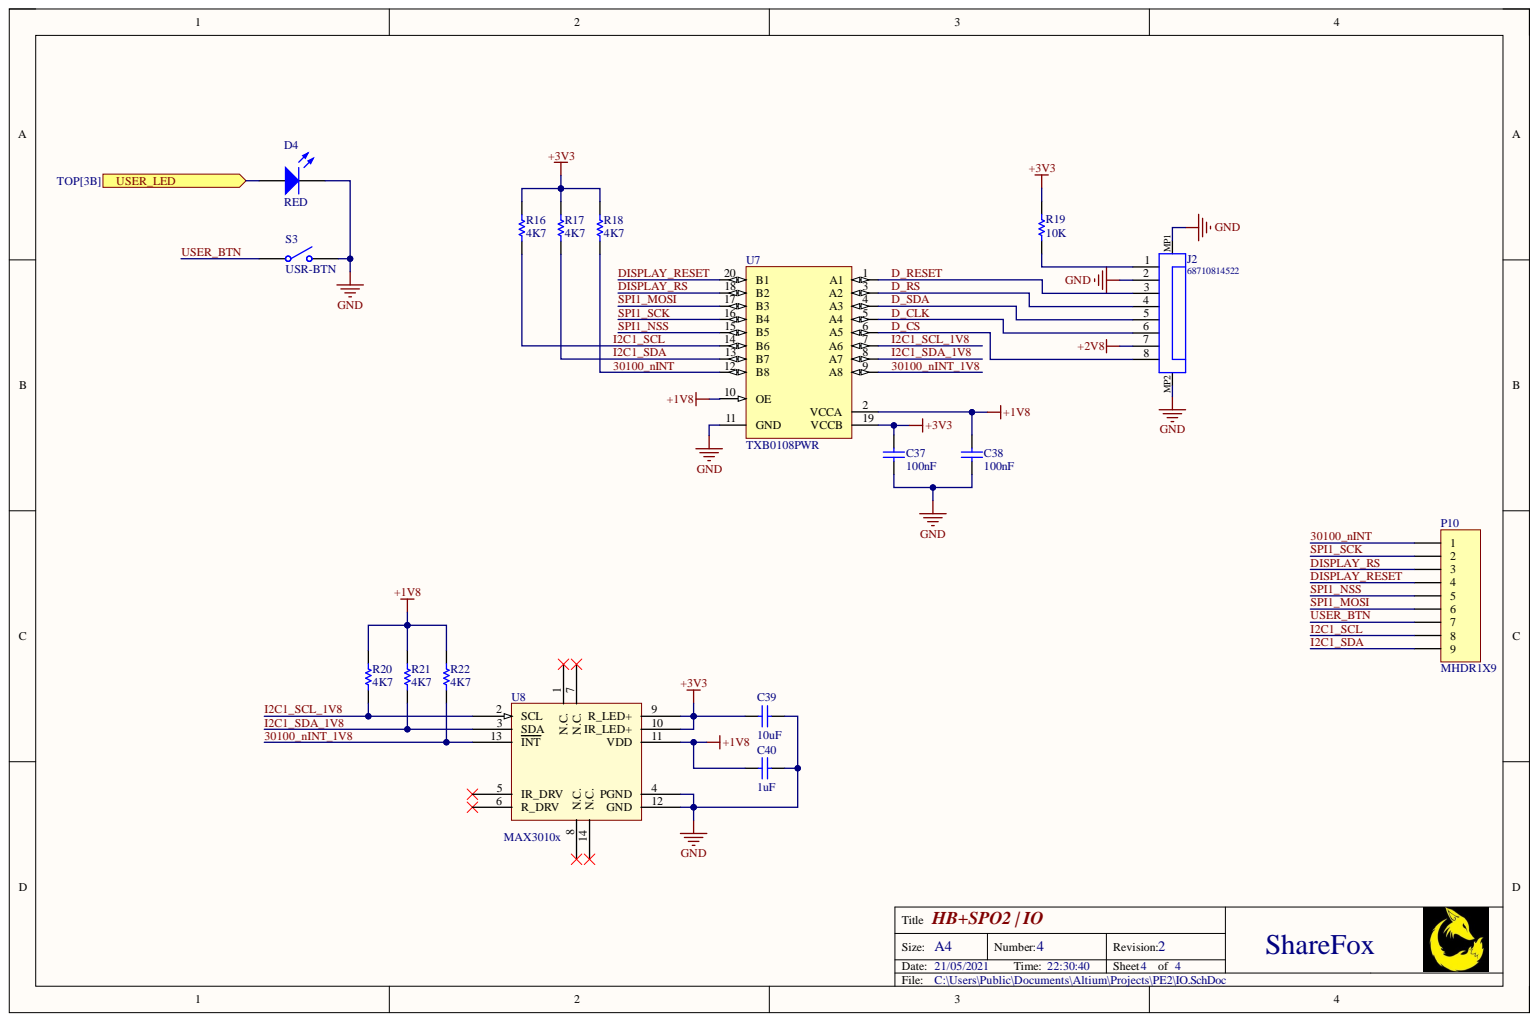
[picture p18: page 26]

HB+SPO2 | IO
Title
C:\Users\Public\Documents\Altium\Projects\PE2\IO.SchDoc

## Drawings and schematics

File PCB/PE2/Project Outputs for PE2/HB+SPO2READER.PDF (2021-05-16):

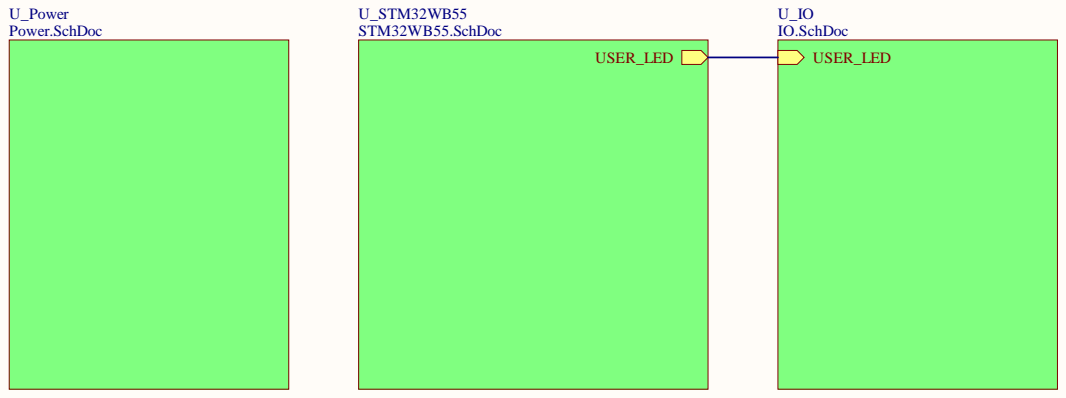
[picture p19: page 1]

HB+SPO2 | Top
Title
C:\Users\Public\Documents\Altium\Projects\PE2\TOP.SchDoc

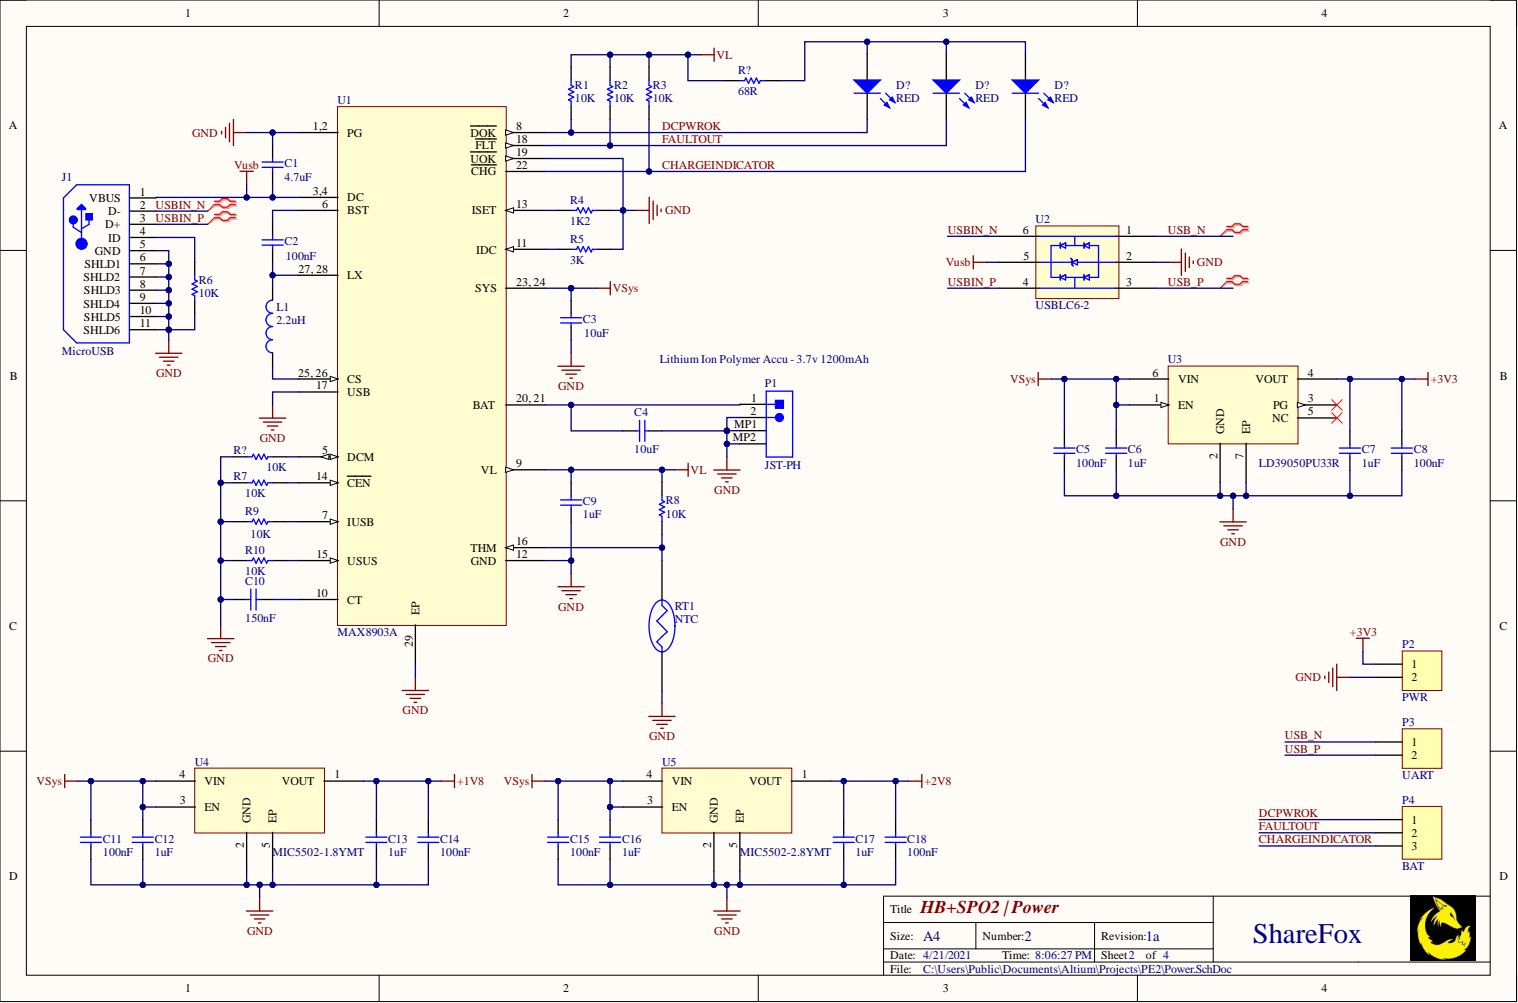
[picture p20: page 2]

DCPW R O K

1 8 | FA U LT O U T
1 9 | CH ARG EIN DICAT O R
2 2

1 3
1 1 1

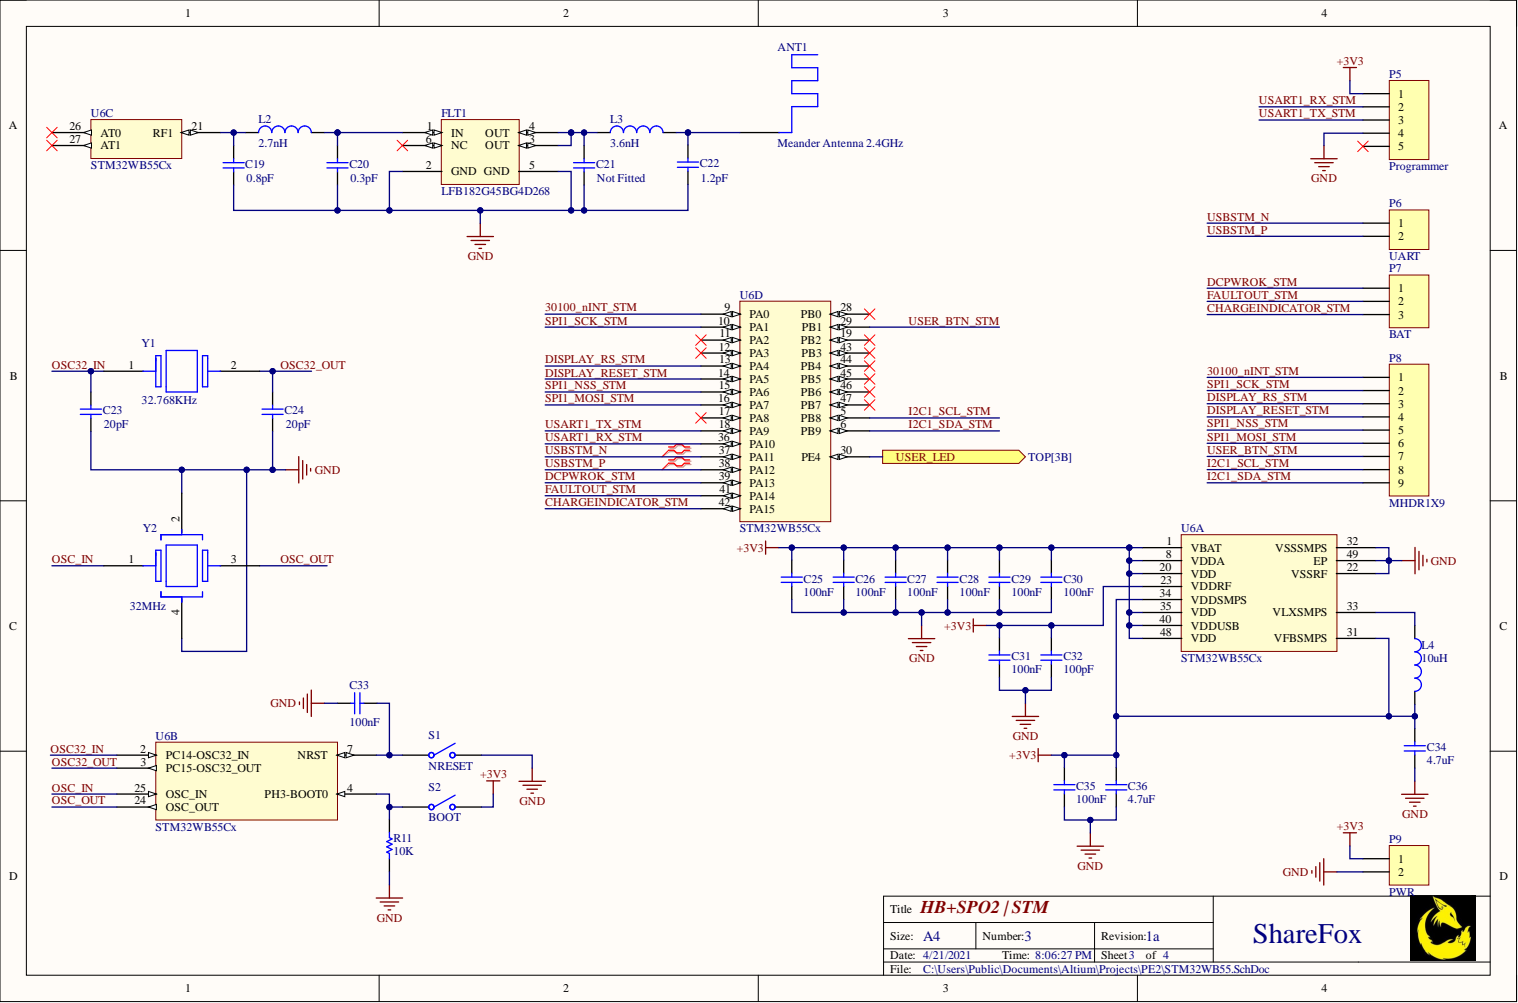
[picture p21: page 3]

VDDRF 23

VDD 35

VDD 48

C:\Users\Public\Documents\Altium\Projects\PE2\STM32WB55.SchDoc

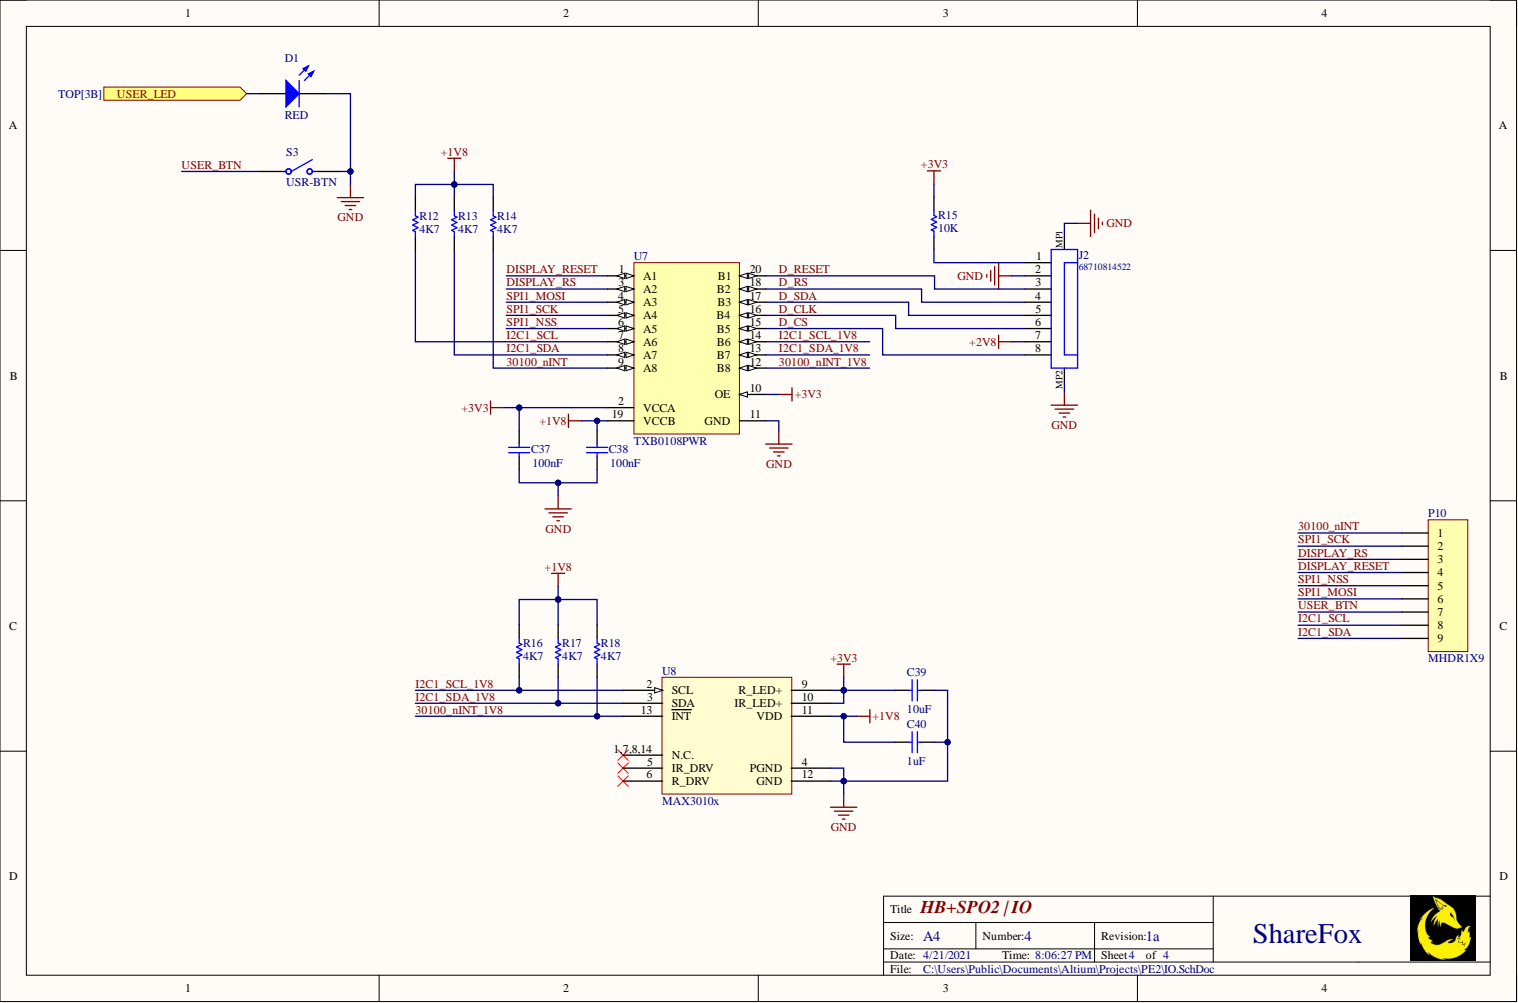
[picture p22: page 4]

DISPLAY_RESET DISPLAY_RS SPI1_MOSI SPI1_SCK SPI1_NSS I2C1_SCL

D_RS | 3
D_SDA | 4

I2C1_SDA | | A7 8 | | 8
30100_nINT | | A8 9 | 30100_nINT_1V8

C:\Users\Public\Documents\Altium\Projects\PE2\IO.SchDoc

Comment | Description | Designator | Footprint | LibRef | Quantity
Meander Antenna 2.4GHz | PCB TRACE DONT TRY TO LOOK FOR PARTS | ANT1 | Meander2.4G | Meander Antenna 2.4GHz | 1
4.7uF | Capacitor | C1, C34, C36 | C_1206 | Cap | 3
100nF | Capacitor | C2, C5, C8, C11, C14, C15, C18, C25, C26, C27, C28, C29, C30, C31, C33, C35, C37, C38 | C_0603 | Cap | 18
10uF | Capacitor | C3, C4, C39 | C_0805 | Cap | 3
1uF | Capacitor | C6, C7, C9, C12, C13, C16, C17, C40 | C_0603 | Cap | 8
150nF | Capacitor | C10 | C_0603 | Cap | 1
0.8pF | Capacitor | C19 | C_0603 | Cap | 1
0.3pF | Capacitor | C20 | C_0603 | Cap | 1
Not Fitted | Capacitor | C21 | C_0603 | Cap | 1
1.2pF | Capacitor | C22 | C_0603 | Cap | 1
20pF | Capacitor | C23, C24 | C_0603 | Cap | 2
100pF | Capacitor | C32 | C_0603 | Cap | 1
RED | Typical RED, GREEN, YELLOW, AMBER GaAs LED | D1, D? | D-0603 | LED2 | 4
LFB182G45BG4D268 | Ultra-small, low-profiled, lightweight band-pass filters. | FLT1 | LFB182G45BG4D268 | LFB182G45BG4D268 | 1
MicroUSB | Micro USB B Type Receptacle, 1.8 A, -55 to 85 degC, 5-Pin SMD, RoHS, Tape and Reel | J1 | FCI-10118194-0001LF-5_V | CMP-2000-05120-1 | 1
68710814522 | SMT ZIF Connectors WR-FPC, Horizontal, Bottom Contact, pitch 0.5mm, 8 pins | J2 | 68710814522 | CMP-1502-01528-1 | 1
2.2uH | Inductor | L1 | L-1008 | Inductor | 1
2.7nH | Inductor | L2 | L-0603 | Inductor | 1
3.6nH | Inductor | L3 | L-0603 | Inductor | 1
10uH | Inductor | L4 | L-0603 | Inductor | 1
JST-PH | Male Header, Pitch 2 mm, 1 x 2 Position, Height 5.5mm, -25 to 85 degC, RoHS, Tape and Reel | P1 | JST- S2B-PH-SM4-TB(LF)(SN)-2_V | CMP-1755-00001-1 | 1
PWR | Header, 2-Pin | P2, P9 | MHDR1X2 | MHDR1X2 | 2
UART | Header, 2-Pin | P3, P6 | MHDR1X2 | MHDR1X2 | 2
BAT | Header, 3-Pin | P4, P7 | MHDR1X3 | MHDR1X3 | 2
Programmer | Header, 5-Pin | P5 | HDR1X5 | MHDR1X5 | 1
MHDR1X9 | Header, 9-Pin | P8, P10 | MHDR1X9 | MHDR1X9 | 2
10K | Resistor | R1, R2, R3, R6, R7, R8, R9, R10, R11, R15, R? | C_0603 | Res1 | 12
1K2 | Resistor | R4 | C_0603 | Res1 | 1
3K | Resistor | R5 | C_0603 | Res1 | 1
4K7 | Resistor | R12, R13, R14, R16, R17, R18 | C_0603 | Res1 | 6
NTC | 2322-640-63103 | RT1 | HDR1X2 | NTC/PTC | 1
NRESET | Single-Pole, Single-Throw Switch | S1 | B3U-1000P-B | SW-SPST | 1
BOOT | Single-Pole, Single-Throw Switch | S2 | B3U-1000P-B | SW-SPST | 1
USR-BTN | Single-Pole, Single-Throw Switch | S3 | HDR1X2 | SW-SPST | 1
MAX8903A | 2A 1-Cell Li+ DC-DC Chargersfor USB and Adapter Power | U1 | QFN28P40S400X400E P260x260 | MAX8903A | 1
USBLC6-2 | Very low capacitance ESD protection | U2 | SOT23-6P95R280X90 | USBLC6-2 | 1
LD39050PU33R | 500mA low quiescent current and low noise voltage regulator | U3 | SON6P95S300X300EP 237x149 | LD39050PUxxR | 1
MIC5502-1.8YMT | Single 300mA LDO | U4 | DFN4P65S100x100EP4 8x48 | MIC550x-x.xYMT | 1
MIC5502-2.8YMT | Single 300mA LDO | U5 | DFN4P65S100x100EP4 8x48 | MIC550x-x.xYMT | 1
STM32WB55Cx | Multiprotocol wireless 32-bit MCU Arm®-based Cortex®-M4 with FPU, Bluetooth® 5 and 802.15.4 radio solution | U6 | QFN48P50S700x700E P560x560 | STM32WB55Cx | 1
TXB0108PWR | TXB0108 8-Bit Bidirectional Voltage-Level Translator with Auto-Direction Sensing and +/- 15-kV ESD Protection, 1.2 to 3.6 V, -40 to 85 degC, 20-Pin TSSOP (PW), Green (RoHS & no Sb/Br), Tape and Reel | U7 | PW0020A_L | CMP-2000-07337-1 | 1
MAX3010x | Pulse Oximeter and Heart-Rate Sensor IC for Wearable Health | U8 | OESIP14R560x330 | MAX3010x | 1
32.768KHz | | Y1 | ECX-31B | XTAL 3215 | 1
32MHz | | Y2 | Y_3225 | XTAL 3225 2_4GND | 1

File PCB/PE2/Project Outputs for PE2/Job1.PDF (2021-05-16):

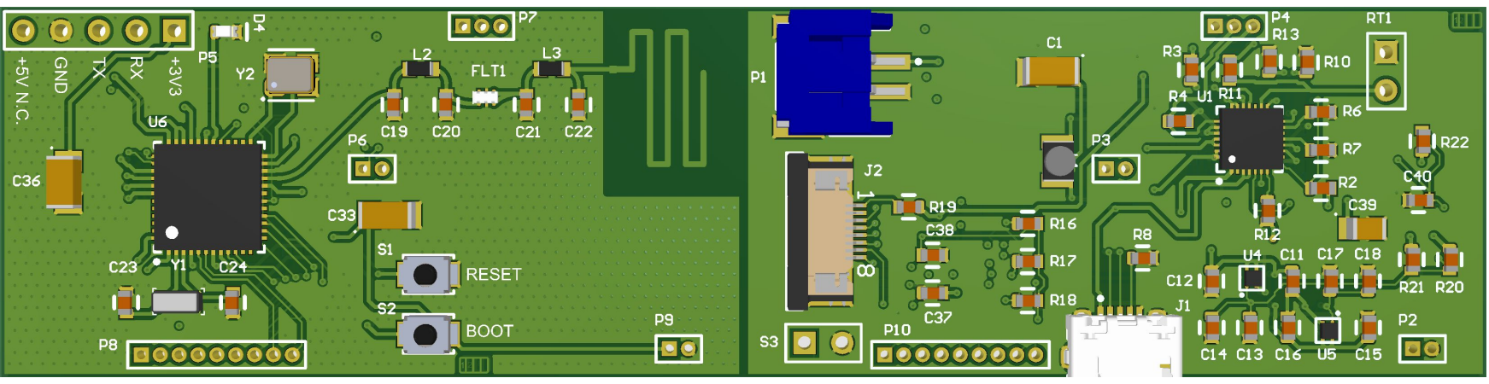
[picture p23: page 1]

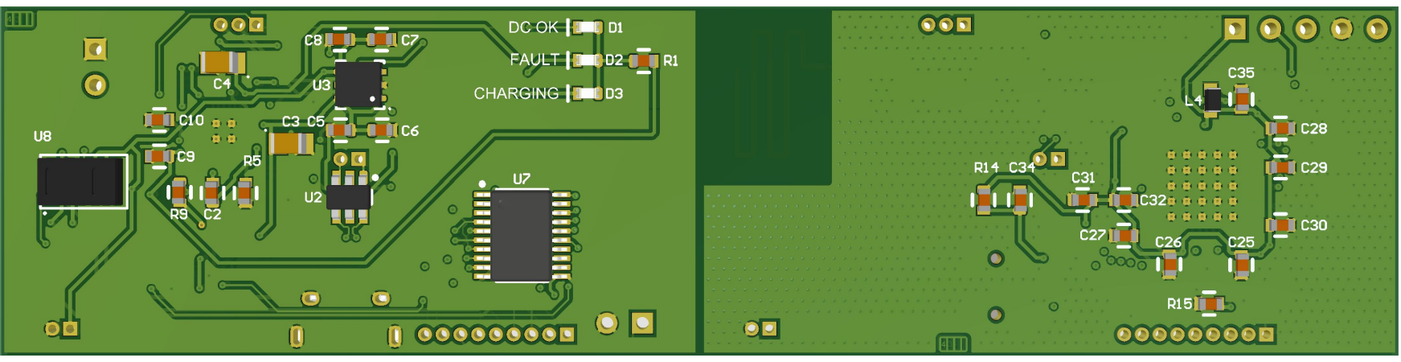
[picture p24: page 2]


HB+SPO2 | Top
Title
C:\Users\Public\Documents\Altium\Projects\PE2\TOP.SchDoc

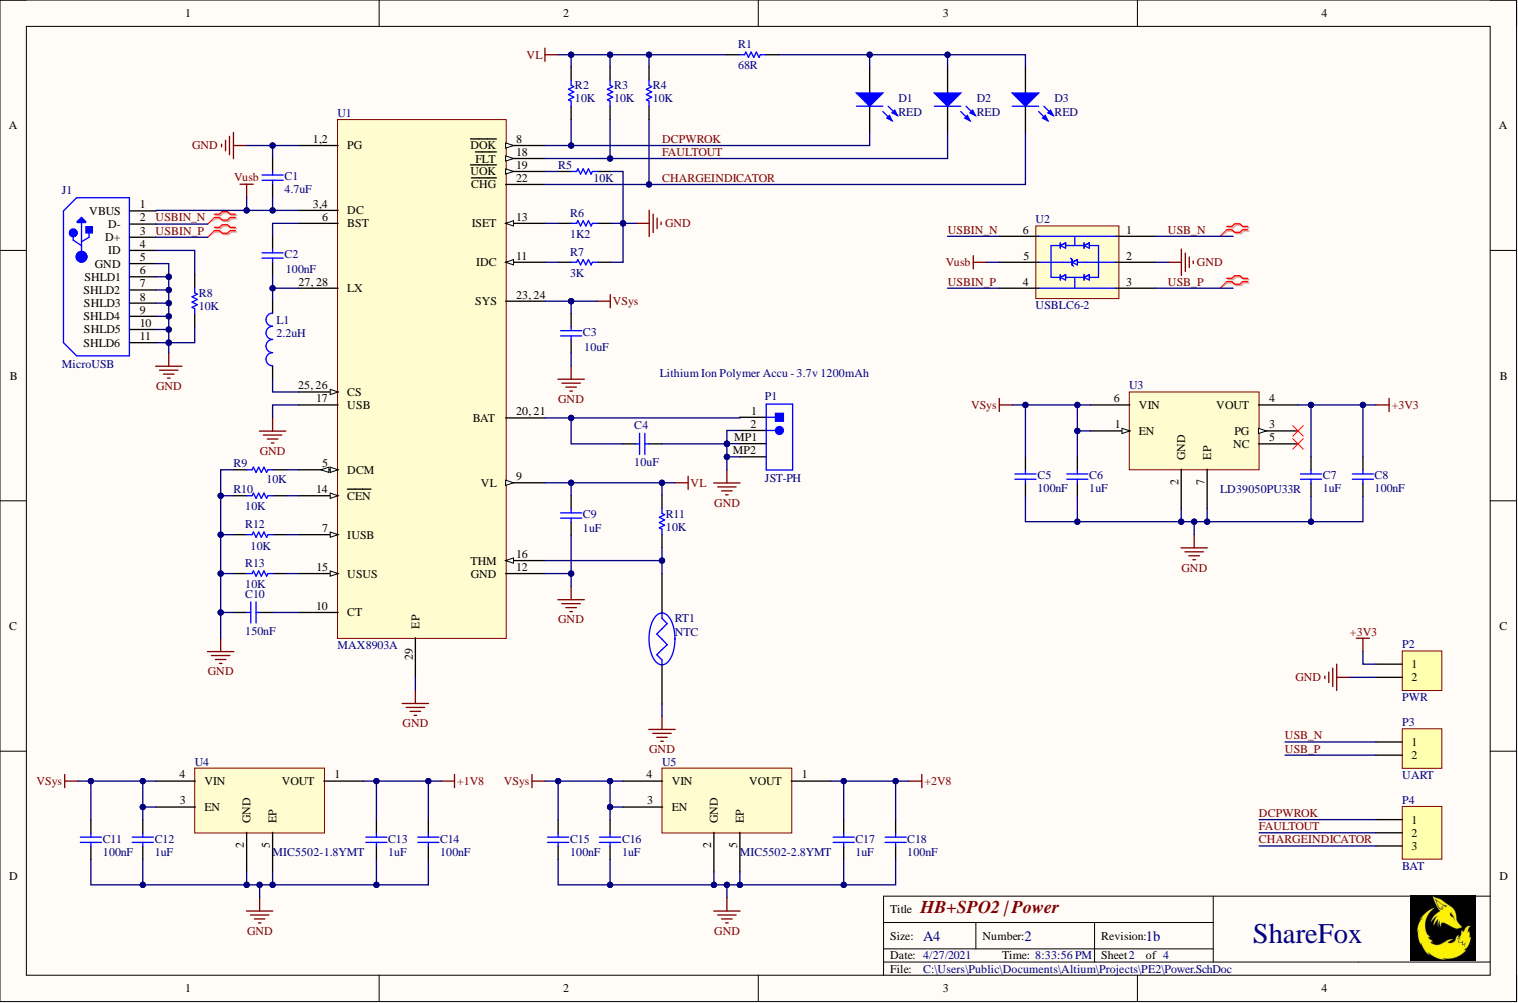
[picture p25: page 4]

DCPWROK

DC 3,4 | | FAULTOUT

R5 | CHARGEINDICATOR

Lithium Ion Polymer Accu - 3.7v 1200mAh

MP1
MP2

C:\Users\Public\Documents\Altium\Projects\PE2\Power.SchDoc

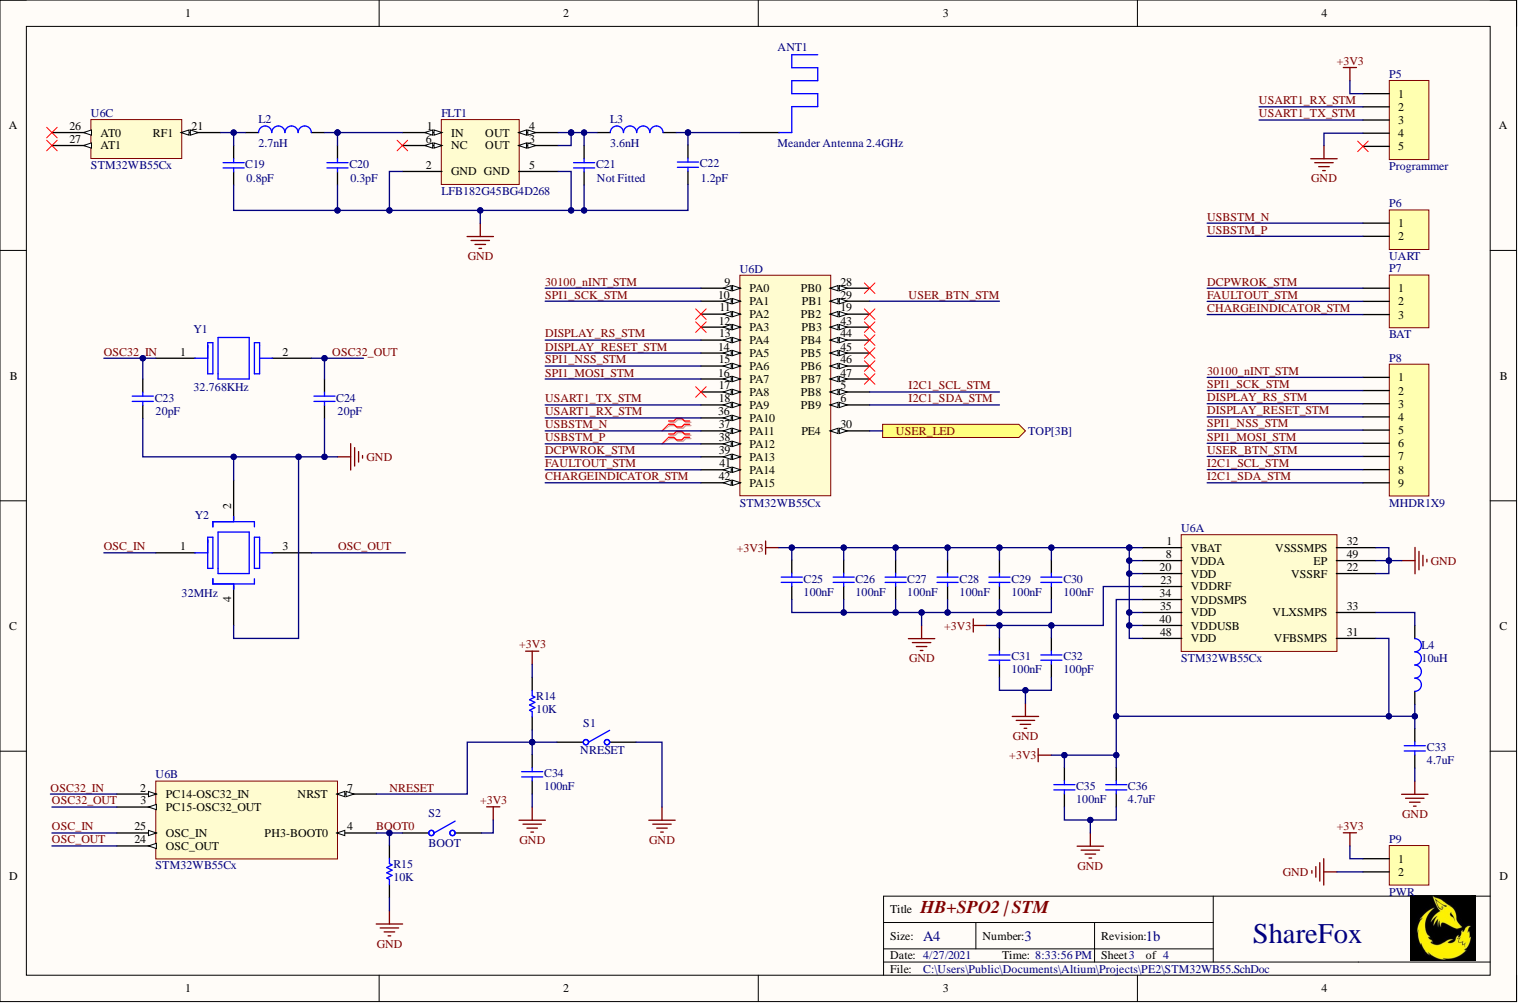
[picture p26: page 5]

VDDRF 23

VDD 35

VDD 48

C:\Users\Public\Documents\Altium\Projects\PE2\STM32WB55.SchDoc

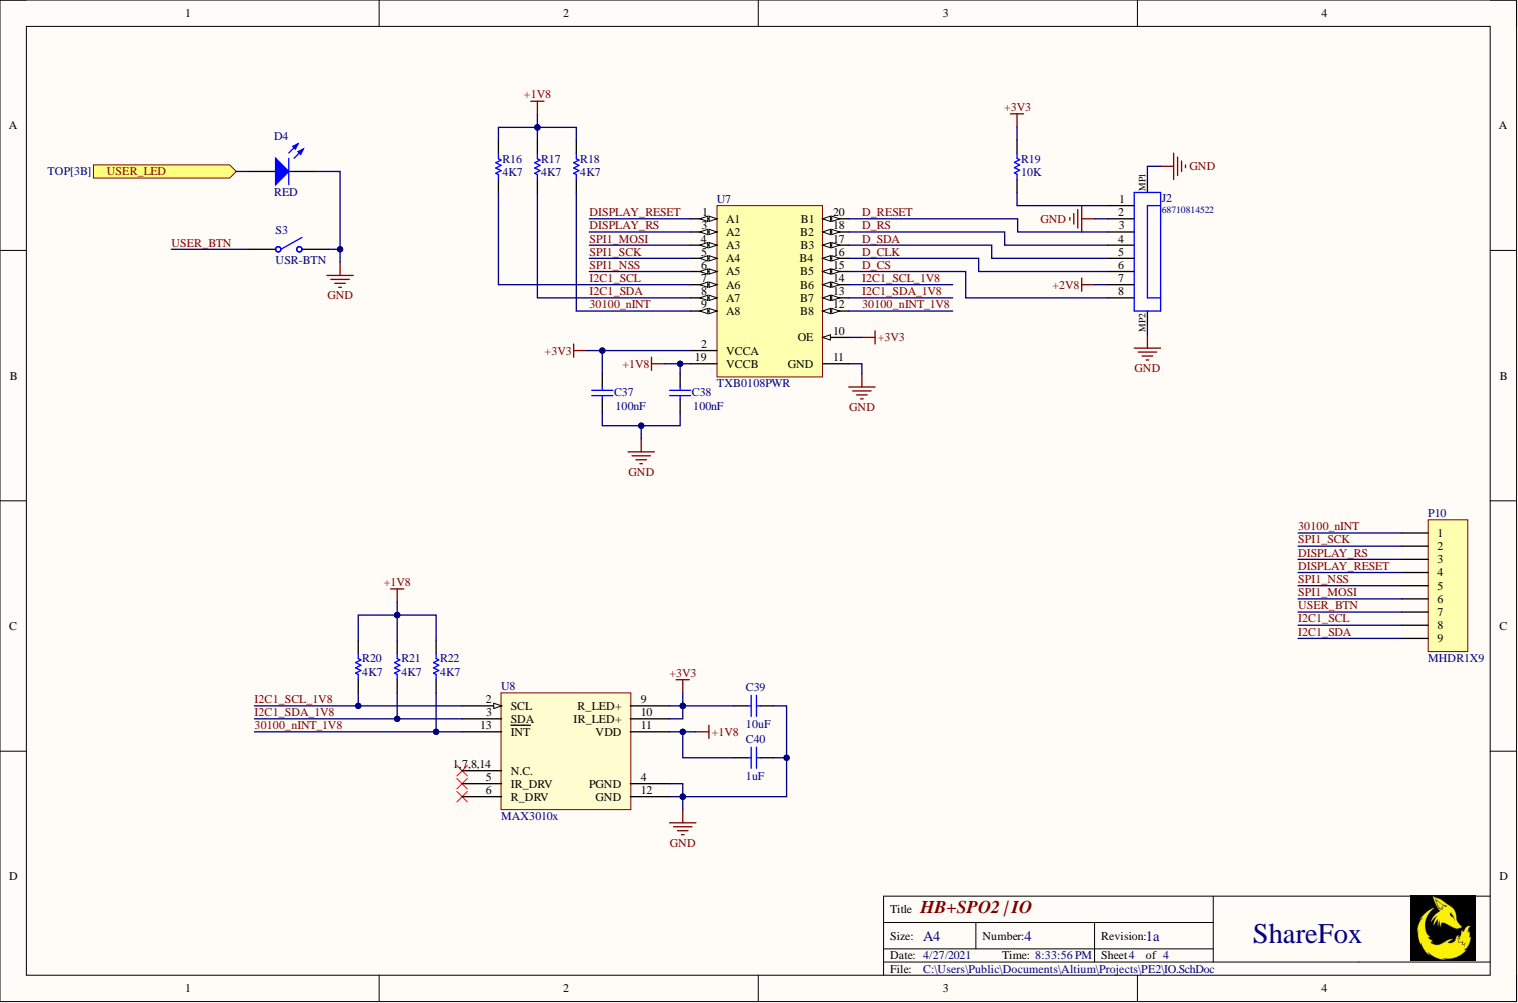
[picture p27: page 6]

DISPLAY_RESET DISPLAY_RS SPI1_MOSI SPI1_SCK SPI1_NSS I2C1_SCL

D_RS | 3
D_SDA | 4

C:\Users\Public\Documents\Altium\Projects\PE2\IO.SchDoc

Comment | Description | Designator | Footprint | LibRef | Quantity
Meander Antenna 2.4GHz | PCB TRACE DONT TRY TO LOOK FOR PARTS | ANT1 | Meander2.4G | Meander Antenna 2.4GHz | 1
4.7uF | Capacitor | C1, C33, C36 | C_1206 | Cap | 3
100nF | Capacitor | C2, C5, C8, C11, C14, C15, C18, C25, C26, C27, C28, C29, C30, C31, C34, C35, C37, C38 | C_0603 | Cap | 18
10uF | Capacitor | C3, C4, C39 | C_0805 | Cap | 3
1uF | Capacitor | C6, C7, C9, C12, C13, C16, C17, C40 | C_0603 | Cap | 8
150nF | Capacitor | C10 | C_0603 | Cap | 1
0.8pF | Capacitor | C19 | C_0603 | Cap | 1
0.3pF | Capacitor | C20 | C_0603 | Cap | 1
Not Fitted | Capacitor | C21 | C_0603 | Cap | 1
1.2pF | Capacitor | C22 | C_0603 | Cap | 1
20pF | Capacitor | C23, C24 | C_0603 | Cap | 2
100pF | Capacitor | C32 | C_0603 | Cap | 1
RED | Typical RED, GREEN, YELLOW, AMBER GaAs LED | D1, D2, D3, D4 | D-0603 | LED2 | 4
LFB182G45BG4D268 | Ultra-small, low-profiled, lightweight band-pass filters. | FLT1 | LFB182G45BG4D268 | LFB182G45BG4D268 | 1
MicroUSB | Micro USB B Type Receptacle, 1.8 A, -55 to 85 degC, 5-Pin SMD, RoHS, Tape and Reel | J1 | FCI-10118194-0001LF-5_V | CMP-2000-05120-1 | 1
68710814522 | SMT ZIF Connectors WR-FPC, Horizontal, Bottom Contact, pitch 0.5mm, 8 pins | J2 | 68710814522 | CMP-1502-01528-1 | 1
2.2uH | Inductor | L1 | L-1008 | Inductor | 1
2.7nH | Inductor | L2 | L-0603 | Inductor | 1
3.6nH | Inductor | L3 | L-0603 | Inductor | 1
10uH | Inductor | L4 | L-0603 | Inductor | 1
JST-PH | Male Header, Pitch 2 mm, 1 x 2 Position, Height 5.5mm, -25 to 85 degC, RoHS, Tape and Reel | P1 | JST- S2B-PH-SM4-TB(LF)(SN)-2_V | CMP-1755-00001-1 | 1
PWR | Header, 2-Pin | P2, P9 | MHDR1X2 | MHDR1X2 | 2
UART | Header, 2-Pin | P3, P6 | MHDR1X2 | MHDR1X2 | 2
BAT | Header, 3-Pin | P4, P7 | MHDR1X3 | MHDR1X3 | 2
Programmer | Header, 5-Pin | P5 | HDR1X5 | MHDR1X5 | 1
MHDR1X9 | Header, 9-Pin | P8, P10 | MHDR1X9 | MHDR1X9 | 2
68R | Resistor | R1 | C_0603 | Res1 | 1
10K | Resistor | R2, R3, R4, R5, R8, R9, R10, R11, R12, R13, R14, R15, R19 | C_0603 | Res1 | 13
1K2 | Resistor | R6 | C_0603 | Res1 | 1
3K | Resistor | R7 | C_0603 | Res1 | 1
4K7 | Resistor | R16, R17, R18, R20, R21, R22 | C_0603 | Res1 | 6
NTC | 2322-640-63103 | RT1 | HDR1X2 | NTC/PTC | 1
NRESET | Single-Pole, Single-Throw Switch | S1 | B3U-1000P-B | SW-SPST | 1
BOOT | Single-Pole, Single-Throw Switch | S2 | B3U-1000P-B | SW-SPST | 1
USR-BTN | Single-Pole, Single-Throw Switch | S3 | HDR1X2 | SW-SPST | 1
MAX8903A | 2A 1-Cell Li+ DC-DC Chargersfor USB and Adapter Power | U1 | QFN28P40S400X400E P260x260 | MAX8903A | 1
USBLC6-2 | Very low capacitance ESD protection | U2 | SOT23-6P95R280X90 | USBLC6-2 | 1
LD39050PU33R | 500mA low quiescent current and low noise voltage regulator | U3 | SON6P95S300X300EP 237x149 | LD39050PUxxR | 1
MIC5502-1.8YMT | Single 300mA LDO | U4 | DFN4P65S100x100EP4 8x48 | MIC550x-x.xYMT | 1
MIC5502-2.8YMT | Single 300mA LDO | U5 | DFN4P65S100x100EP4 8x48 | MIC550x-x.xYMT | 1
STM32WB55Cx | Multiprotocol wireless 32-bit MCU Arm®-based Cortex®-M4 with FPU, Bluetooth® 5 and 802.15.4 radio solution | U6 | QFN48P50S700x700E P560x560 | STM32WB55Cx | 1
TXB0108PWR | TXB0108 8-Bit Bidirectional Voltage-Level Translator with Auto-Direction Sensing and +/- 15-kV ESD Protection, 1.2 to 3.6 V, -40 to 85 degC, 20-Pin TSSOP (PW), Green (RoHS & no Sb/Br), Tape and Reel | U7 | PW0020A_L | CMP-2000-07337-1 | 1
MAX3010x | Pulse Oximeter and Heart-Rate Sensor IC for Wearable Health | U8 | OESIP14R560x330 | MAX3010x | 1
32.768KHz | | Y1 | ECX-31B | XTAL 3215 | 1
32MHz | | Y2 | Y_3225 | XTAL 3225 2_4GND | 1

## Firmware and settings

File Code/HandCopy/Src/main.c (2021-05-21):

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
/* Includes ------------------------------------------------------------------*/
#include "main.h"

/* USER CODE BEGIN Includes */
#include "app_entry.h"
#include "MAX30102.h"
#include "stm32_seq.h"
#include "st7735.h"
#include "fonts.h"
#include "home_data.h"
#include "second_data.h"
#include <string.h>
#include <stdio.h>
#include <zero_data.h>
/* USER CODE END Includes */

I2C_HandleTypeDef hi2c1;

IPCC_HandleTypeDef hipcc;

RTC_HandleTypeDef hrtc;

SPI_HandleTypeDef hspi1;

UART_HandleTypeDef huart1;

PCD_HandleTypeDef hpcd_USB_FS;

/* USER CODE BEGIN PV */
uint8_t r =  0 ;

/* USER CODE END PV */

void SystemClock_Config(void);
static void MX_GPIO_Init(void);
static void MX_USART1_UART_Init(void);
static void MX_RF_Init(void);
static void MX_RTC_Init(void);
static void MX_I2C1_Init(void);
static void MX_USB_PCD_Init(void);
static void MX_IPCC_Init(void);
static void MX_SPI1_Init(void);
/* USER CODE BEGIN 0 */
uint32_t heartRate;
/* USER CODE END 0 */

/**
  * @brief  The application entry point.
  * @retval int
  */
int main(void)
{
  /* MCU Configuration--------------------------------------------------------*/

  /* Reset of all peripherals, Initializes the Flash interface and the Systick. */
  HAL_Init();

  /* Configure the system clock */
  SystemClock_Config();

  /* IPCC initialisation */
   MX_IPCC_Init();

  /* Initialize all configured peripherals */
  MX_GPIO_Init();
  MX_USART1_UART_Init();
  MX_RF_Init();
  MX_RTC_Init();
  MX_I2C1_Init();
  MX_USB_PCD_Init();
  MX_SPI1_Init();
  /* USER CODE BEGIN 2 */
  ST7735_Init ();
  ST7735_SetRotation(3);
  ST7735_FillScreen (ST7735_CustomBG);
  ST7735_DrawString ( 50 , 0 , "SPO2" , Font_16x26, ST7735_WHITE, ST7735_CustomBG);
  ST7735_DrawString ( 35 , 25 , "Reader" , Font_16x26, ST7735_WHITE, ST7735_CustomBG);
  ST7735_DrawString ( 75 , 55, "by" , Font_7x10, ST7735_WHITE, ST7735_CustomBG);
  ST7735_DrawString ( 15 , 70 , "Lieselotte en Glenn" , Font_7x10, ST7735_WHITE, ST7735_CustomBG);
  UTIL_SEQ_Init();
  StartSensor();
  BeginBerekening();
  InterruptsSwitch();
  /* USER CODE END 2 */

  /* Init code for STM32_WPAN */
  APPE_Init();
  /* Infinite loop */
  /* USER CODE BEGIN WHILE */
  while (1)
  {
    /* USER CODE END WHILE */

    /* USER CODE BEGIN 3 */

	  UTIL_SEQ_Run( ~0);
  }
  /* USER CODE END 3 */
}

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
/* USER CODE BEGIN 4 */
	void HAL_GPIO_EXTI_Callback(uint16_t pinINter)
	{
   // interrupt routine voor MAX
		if (pinINter == MAX_nINT_Pin )
		{
			// Hier functie oproepen met SEQ
			InterruptsSwitch();
		}
	}
/* USER CODE END 4 */
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


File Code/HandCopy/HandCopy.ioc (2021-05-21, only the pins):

Mcu.UserName=STM32WB55RGVx
PA0.GPIO_Label=MAX_nINT
PA0.Signal=GPXTI0
PA1.Signal=SPI1_SCK
PA10.Signal=USART1_RX
PA11.Signal=USB_DM
PA12.Signal=USB_DP
PA13.Signal=SYS_JTMS-SWDIO
PA14.Signal=SYS_JTCK-SWCLK
PA4.GPIO_Label=ST7735_DC
PA4.Signal=GPIO_Output
PA5.GPIO_Label=ST7735_RES
PA5.Signal=GPIO_Output
PA6.GPIO_Label=ST7735_CS
PA6.Signal=GPIO_Output
PA7.Signal=SPI1_MOSI
PA9.Signal=USART1_TX
PB0.GPIO_Label=LED_GREEN
PB0.Signal=GPIO_Output
PB1.GPIO_Label=Button_Pin
PB1.Signal=GPIO_Input
PB2.Signal=RTC_OUT2
PB5.GPIO_Label=LED_BLUE
PB5.Signal=GPIO_Output
PB8.Signal=I2C1_SCL
PB9.Signal=I2C1_SDA
PC14-OSC32_IN.Signal=RCC_OSC32_IN
PC15-OSC32_OUT.Signal=RCC_OSC32_OUT
PC4.GPIO_Label=BUTTON_SW1
PC4.Signal=GPXTI4
PE4.GPIO_Label=LED_Pin
PE4.Signal=GPIO_Output

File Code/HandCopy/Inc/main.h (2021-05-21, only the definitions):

#define MAX_nINT_Pin GPIO_PIN_0
#define MAX_nINT_GPIO_Port GPIOA
#define MAX_nINT_EXTI_IRQn EXTI0_IRQn
#define ST7735_DC_Pin GPIO_PIN_4
#define ST7735_DC_GPIO_Port GPIOA
#define ST7735_RES_Pin GPIO_PIN_5
#define ST7735_RES_GPIO_Port GPIOA
#define ST7735_CS_Pin GPIO_PIN_6
#define ST7735_CS_GPIO_Port GPIOA
#define BUTTON_SW1_Pin GPIO_PIN_4
#define BUTTON_SW1_GPIO_Port GPIOC
#define LED_GREEN_Pin GPIO_PIN_0
#define LED_GREEN_GPIO_Port GPIOB
#define Button_Pin_Pin GPIO_PIN_1
#define Button_Pin_GPIO_Port GPIOB
#define LED_Pin_Pin GPIO_PIN_4
#define LED_Pin_GPIO_Port GPIOE
#define LED_BLUE_Pin GPIO_PIN_5
#define LED_BLUE_GPIO_Port GPIOB

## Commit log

2020-11-30 +Library folder +PCB folder +Code Folder
    [DFN.PcbLib, IO.SchDoc, MICREL.SchLib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]
2021-05-02 Add files via upload
    Capture Logic Analyzer, adres van MAX30102 wordt uitgestuurd via I2C
    werkt.
2021-05-16 update V2
    [1.27to2.54.SchDoc, HalfPCB1.PcbDoc, HalfPCB2.PcbDoc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]
2021-05-21 +Code +Doc
    Added our current version of the code
    Added a folder Doc for our documents
    [HandCopy Run.cfg]

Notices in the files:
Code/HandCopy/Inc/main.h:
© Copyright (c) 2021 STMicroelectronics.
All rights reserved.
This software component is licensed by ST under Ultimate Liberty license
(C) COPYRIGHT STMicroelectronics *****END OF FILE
